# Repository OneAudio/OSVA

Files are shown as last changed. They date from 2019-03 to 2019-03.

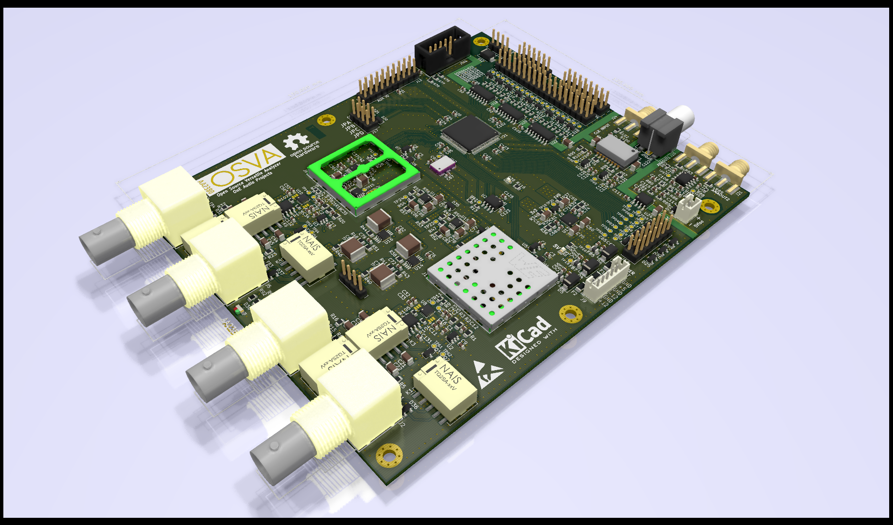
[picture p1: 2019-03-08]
AA2380V1.00_Final/AA2380v1.00_3Dview.png

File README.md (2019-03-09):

# OSVA 
## Open source versatile analyzer (2 Channels 24 bits 1536 kSPS)

The OSVA project is a 2 channels signal analyzer using high resolution SAR ADC (LTC2380-24).
It has been designed to be used as system analyser but using standard digital audio interface.

The OSVA project include 4 sub-design (boards):
-----------------------------------------------
1. AA2380  - 2 channels ADC board : It is the main board.
2. AA10M08 - CPLD digital board : Optional board
3. AAPSU01 - Low noise SMSP board
4. AACMD01 - Command panel board

 The AA2380 main specifications are :
 ------------------------------------
* 2 ADC Channels using LTC2380-24 (or compatible device)
* 24 bits resolution up to 1536 ksps
* 10Vpp full-scale signal sensitivity (default)
* Single-ended or fully differential mode (switchable)
* 2 analog anti-alias filter cuttoff (38.4kHz/384kHz by default)
* On board ultra low jitter clock
* Direct SPDIF stereo output with support up to 192kHz sampling.
* SinC type Digital filter (x1 to x32 selectable).
* isolated 100MHz External clock input (for sampling synchronisation)
* 2 isolated analog output for coherant sampling capability.
* isolated High speed digital interface to connect :
	- AA10M08 dedicated Digital board
	- USB-Streamer from mini-DSP for 4 channels 24/192k to USB
	- SDR-Widget board for 24/192k I2S to USB

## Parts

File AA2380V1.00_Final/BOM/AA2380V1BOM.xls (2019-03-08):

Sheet: Feuille1
Kicad_Projects/AA2380V1/AA2380V1.sch
Ref | Qnty | Value | Footprint | Description | Order code | Distributor | Unit price € | in stock
C1, C2, C3, C4, C5, C6, C7, C9, C10, C16, C17, C18, C19, C20, C25, C32, C39, C40, C41, C42, C43, C48, C55, C57, C88, C89, C90, C91, C92, C93, C94, C95, C97, C100, C101, C102, C103, C105, C106, C109, C111, C118, C119, C124, C125, C127, C129, C131, C132 | 49 | 100nF/16V | Device:Capacitor_SMD:C_0603_1608Metric | Unpolarized capacitor, small symbol | 710-885012206071 | Mouser | 0.03 €
C8, C11, C33, C34, C56, C58, C87, C98, C99, C104, C107, C123 | 12 | 2.2uF/16V | Device:Capacitor_SMD:C_0603_1608Metric | Unpolarized capacitor, small symbol | 81-GRM188C71C225KE1D | Mouser | 0.26 €
C12, C13, C14, C23, C35, C36, C37, C46 | 8 | 10uF/6.3V | Device:Capacitor_SMD:C_0603_1608Metric | Unpolarized capacitor, small symbol | 81-GRM188R60J106KE7D | Mouser | 0.16 €
C15, C38 | 2 | 47uF/6.3V | Device:Capacitor_SMD:C_1210_3225Metric | Unpolarized capacitor, small symbol | 81-GCM32ER70J476KE9L | Mouser | 1.07 €
C21, C30, C44, C53 | 4 | 2.7nF/100V COG | Device:Capacitor_SMD:C_1206_3216Metric | Unpolarized capacitor, small symbol | 80-C1206C272J1G | Mouser | 0.58 €
C22, C31, C45, C54 | 4 | 270pF/100V COG | Device:Capacitor_SMD:C_1206_3216Metric | Unpolarized capacitor, small symbol | 77-VJ1206A271JXBAT | Mouser | 0.20 €
C24, C29, C47, C52 | 4 | 6.8nF/100V COG | Device:Capacitor_SMD:C_1206_3216Metric | Unpolarized capacitor, small symbol | 710-885012008078 | Mouser | 0.48 €
C26, C49 | 2 | 390pF/100V COG | Device:Capacitor_SMD:C_1206_3216Metric | Unpolarized capacitor, small symbol | 77-VJ1206A391JXBMT | Mouser | 0.15 €
C27, C50 | 2 | 3.9nF/100V COG | Device:Capacitor_SMD:C_1206_3216Metric | Unpolarized capacitor, small symbol | 810-C3216C0G2A392J | Mouser | 0.23 €
C28, C51 | 2 | 3.3nF/100V COG | Device:Capacitor_SMD:C_1206_3216Metric | Unpolarized capacitor, small symbol | 710-885012008076 | Mouser | 0.36 €
C59, C60, C69, C70, C77, C84 | 6 | 22uF/16V X7R | Device:Capacitor_SMD:C_1206_3216Metric | Unpolarized capacitor, small symbol | 81-GRM31CC71C226ME1L | Mouser | 0.98 €
C61, C71, C72, C76, C79, C82, C120, C126 | 8 | 10nF/25V X7R | Device:Capacitor_SMD:C_0603_1608Metric | Unpolarized capacitor, small symbol | 710-885012206065 | Mouser | 0.04 €
C62, C63, C64, C65, C66, C67, C68, C74, C110, C113 | 10 | 1uF/25V X7R | Device:Capacitor_SMD:C_0603_1608Metric | Unpolarized capacitor, small symbol | 710-885012106022 | Mouser | 0.08 €
C73, C75, C80, C81 | 4 | 22uF/25V X7R | Device:Capacitor_SMD:C_2220_5650Metric | Unpolarized capacitor, small symbol | 810-C5750X5R1E226M2A | Mouser | 2.15 €
C78, C85 | 2 | 22uF/16V X7R | AA2380:AA2380V1:C_1206_3216Metric_4-PADS | Unpolarized capacitor 4 wires (with sense) | 81-GRM31CC71C226ME1L | Mouser | 0.98 €
C83, C86 | 2 | 22uF/6v3 | Device:Capacitor_SMD:C_1206_3216Metric | Unpolarized capacitor, small symbol | 710-885012108003 | Mouser | 0.66 €
C96, C122, C128, C130 | 4 | 1nF/500V X7R | Device:Capacitor_SMD:C_1206_3216Metric | Unpolarized capacitor, small symbol | 710-885342208006 | Mouser | 0.10 €
C108, C117 | 2 | 10nF 1% | Device:Capacitor_SMD:C_0603_1608Metric | Unpolarized capacitor, small symbol | 81-GRM1885C1H103FA1D | Mouser | 0.25 €
C112, C116 | 2 | 2.7nF 1% | Device:Capacitor_SMD:C_0603_1608Metric | Unpolarized capacitor, small symbol | 81-GRM1885C1H272GA1D | Mouser | 0.24 €
C114, C115 | 2 | 1nF 1% | Device:Capacitor_SMD:C_0603_1608Metric | Unpolarized capacitor, small symbol | 81-GRM1885C1H102FA1D | Mouser | 0.10 €
C121 | 1 | 2u2/16V | Device:Capacitor_SMD:C_0603_1608Metric | Unpolarized capacitor, small symbol | 81-GRM188C81C225KA2D | Mouser | 0.23 €
D1, D2, D36, D37 | 4 | SZNUP2105L | Power_Protection:Package_TO_SOT_SMD:SOT-23 | Dual Line CAN Bus Protector, 24Vrwm, Automotive Grade | 863-SZNUP2105LT1G | Mouser | 0.43 €
D3, D19, D38 | 3 | LED_Small_ALT | Device:LED_SMD:LED_0603_1608Metric | Light emitting diode, small symbol, filled shape | 710-150060GS75000 | Mouser | 0.13 €
D4, D5 | 2 | P4SMA16A | AA2380:Diode_SMD:D_SMA | 400W unidirectional Voltage Suppressor, (SMA) | 576-P4SMA16A | Mouser | 0.49 €
D6 | 1 | P4SMA6.8A | AA2380:Diode_SMD:D_SMA | 400W unidirectional Voltage Suppressor, (SMA) | 576-P4SMA6.8A | Mouser | 0.49 €
D7 | 1 | BAT54C | Diode:Package_TO_SOT_SMD:SOT-23 | dual schottky barrier diode, common cathode | 863-BAT54CLT1G | Mouser | 0.12 €
D8, D35 | 2 | BAV99 | Diode:Package_TO_SOT_SMD:SOT-23 | BAV99 High-speed switching diodes | 863-BAV99LT1G | Mouser | 0.12 €
D9, D10, D11, D13, D14, D15, D16, D17, D18, D20, D21, D22, D23, D24, D25, D26, D27 | 17 | PESD5V0X1BT | AA2380:Package_TO_SOT_SMD:SOT-23 | Dual low capacitance unidirectional ESD Protector, 5Vrwm | 771-PESD5V0X1BT-T/R | Mouser | 0.25 €
D12 | 1 | SMLVT3V3_0 | AA2380:Diode_SMD:D_SMB | 600W unidirectional low voltage (3v3) Transient Voltage Suppressor, DO-201AC (SMB) | 511-SMLVT3V3 | Mouser | 0.58 €
D28, D29, D31, D32, D33 | 5 | MBR0540 | Diode:Diode_SMD:D_SOD-123 | 40V 0.5A Schottky Power Rectifier Diode, SOD-123 | 863-MBR0540T1G | Mouser | 0.27 €
D30, D34 | 2 | APFA3010 | LED:AA2380V1:LED_Kingbright_APFA3010_3x1.5mm_Horizontal | LED RGB, Common Anode, SMD, 3.0x1.5mm, Horizontal | 604-APFA3010LSEEZGKQ | Mouser | 0.79 €
F1 | 1 | 500mA | Device:Fuse:Fuse_1206_3216Metric | Resettable fuse, polymeric positive temperature coefficient, small symbol | 650-NANOC050F/13.2-2 | Mouser | 0.30 €
F2, F3 | 2 | 200mA | Device:Fuse:Fuse_1206_3216Metric | Resettable fuse, polymeric positive temperature coefficient, small symbol | 650-NANOSMDC020F-2 | Mouser | 0.37 €
FB1, FB2, FB3, FB4 | 4 | 600R@100M | AA2380:Inductor_SMD:L_0805_2012Metric_Pad1.15x1.40mm_HandSolder | Ferrite bead | 710-7427920415 | Mouser | 0.19 €
FB5, FB6, FB7 | 3 | 600/100M | AA2380:Inductor_SMD:L_0805_2012Metric_Pad1.15x1.40mm_HandSolder | Ferrite bead | 710-7427920415 | Mouser | 0.19 €
J1, J8 | 2 | RF_Shield_Two_Pieces | Device:AA2380V1:wurth-shield | Two-piece EMI RF shielding cabinet | 710-36103255S | Mouser | 1.29 €
J2, J4, J5, J7 | 4 | Conn_Coaxial | Connector:AA2380V1:BNC_90_73137-5003 | coaxial connector (BNC, SMA, SMB, SMC, Cinch/RCA, ...) | 538-73137-5003 | Mouser | 1.72 €
J9 | 1 | Conn_01x06_Male | Connector:Connector_JST:JST_PH_B6B-PH-K_1x06_P2.00mm_Vertical | Generic connector, single row, 01x06, script generated (kicad-library-utils/schlib/autogen/connector/) | 455-1708-ND | Digikey | 0.29 €
J10 | 1 | Conn_01x04_Female | Connector:Connector_PinHeader_2.54mm:PinHeader_1x04_P2.54mm_Vertical | Generic connector, single row, 01x04, script generated (kicad-library-utils/schlib/autogen/connector/) | 855-M20-7820446 | Mouser | 0.68 €
J11 | 1 | Conn_02x06_Odd_Even | Connector_Generic:Connector_PinHeader_2.54mm:PinHeader_2x06_P2.54mm_Vertical | Generic connector, double row, 02x06, odd/even pin numbering scheme (row 1 odd numbers, row 2 even numbers), script generated (kicad-library-utils/schlib/autogen/connector/) | 855-M20-9760642 | Mouser | 0.38 €
J12 | 1 | Conn_02x10_Odd_Even | Connector_Generic:Connector_PinHeader_2.54mm:PinHeader_2x10_P2.54mm_Vertical | Generic connector, double row, 02x10, odd/even pin numbering scheme (row 1 odd numbers, row 2 even numbers), script generated (kicad-library-utils/schlib/autogen/connector/) | 855-M20-9761042 | Mouser | 0.64 €
J13 | 1 | Conn_02x08_Odd_Even | Connector_Generic:Connector_PinHeader_2.54mm:PinHeader_2x08_P2.54mm_Vertical | Generic connector, double row, 02x08, odd/even pin numbering scheme (row 1 odd numbers, row 2 even numbers), script generated (kicad-library-utils/schlib/autogen/connector/) | 855-M20-9760842 | Mouser | 0.57 €
J14 | 1 | Conn_01x04 | Connector_Generic:Connector_PinHeader_2.54mm:PinHeader_1x04_P2.54mm_Vertical | Generic connector, single row, 01x04, script generated (kicad-library-utils/schlib/autogen/connector/) | 855-M20-9730445 | Mouser | 0.21 €
J16 | 1 | Conn_02x18_Odd_Even | Connector_Generic:Connector_PinHeader_2.54mm:PinHeader_2x18_P2.54mm_Vertical | Generic connector, double row, 02x18, odd/even pin numbering scheme (row 1 odd numbers, row 2 even numbers), script generated (kicad-library-utils/schlib/autogen/connector/) | 855-M20-9761846 | Mouser | 0.80 €
J17 | 1 | Conn_02x04_Odd_Even | Connector_Generic:Connector_PinHeader_2.54mm:PinHeader_2x04_P2.54mm_Vertical | Generic connector, double row, 02x04, odd/even pin numbering scheme (row 1 odd numbers, row 2 even numbers), script generated (kicad-library-utils/schlib/autogen/connector/) | 855-M20-9760442 | Mouser | 0.29 €
J18 | 1 | Conn_02x07_Odd_Even | Connector_Generic:Connector_PinHeader_2.54mm:PinHeader_2x07_P2.54mm_Vertical | Generic connector, double row, 02x07, odd/even pin numbering scheme (row 1 odd numbers, row 2 even numbers), script generated (kicad-library-utils/schlib/autogen/connector/) | 855-M20-9760746 | Mouser | 0.41 €
J19 | 1 | Conn_02x05_Odd_Even | Connector_Generic:Connector_IDC:IDC-Header_2x05_P2.54mm_Vertical | Generic connector, double row, 02x05, odd/even pin numbering scheme (row 1 odd numbers, row 2 even numbers), script generated (kicad-library-utils/schlib/autogen/connector/) | 855-M20-9760542 | Mouser | 0.36 €
J20, J21, J24 | 3 | Conn_Coaxial | Connector:Connector_Coaxial:SMA_Molex_73251-1153_EdgeMount_Horizontal | coaxial connector (BNC, SMA, SMB, SMC, Cinch/RCA, ...) | 538-73251-1150 | Mouser | 3.05 €
J22 | 1 | Conn_02x01 | Connector_Generic:Connector_JST:JST_PH_B2B-PH-K_1x02_P2.00mm_Vertical | Generic connector, double row, 02x01, this symbol is compatible with counter-clockwise, top-bottom and odd-even numbering schemes., script generated (kicad-library-utils/schlib/autogen/connector/) | 455-1704-ND | Digikey | 0.15 €
J23 | 1 | Conn_Coaxial | Connector:AA2380V1:RCA | coaxial connector (BNC, SMA, SMB, SMC, Cinch/RCA, ...) | 806-KLPX-0848A-2-O | Mouser | 0.74 €
K1, K2, K3, K4, K5, K6 | 6 | RELAY_DPDT | AA2380:Relay_SMD:Relay_DPDT_Omron_G6H-2F | Small signal relay, 5V coil ??mW DPDT ??V/ | 769-TQ2SL-5V | Mouser | 3.21 €
Q1, Q2, Q3, Q4 | 4 | BSS138 | Transistor_FET:Package_TO_SOT_SMD:SOT-23 | 50V Vds, 0.22A Id, N-channel MOSFET, SOT-23 | 771-BSS138P215 | Mouser | 0.21 €
R1, R2, R18, R20, R79 | 5 | 1k | Device:Resistor_SMD:R_0805_2012Metric | Resistor | 71-CRCW08051K00FKEB | Mouser | 0.11 €
R3, R21 | 2 | 249 | Device:Resistor_SMD:R_0805_2012Metric | Resistor | 71-CRCW0805-249-E3 | Mouser | 0.11 €
R4, R5, R15, R16, R22, R23, R31, R32 | 8 | 1k 0.5% | Device:Resistor_SMD:R_0805_2012Metric | Resistor | 754-RG2012P-102DT5 | Mouser | 0.19 €
R6, R12, R24, R30 | 4 | 549 0.5% | Device:Resistor_SMD:R_0805_2012Metric | Resistor | 754-RG2012P-5490DT5 | Mouser | 0.19 €
R7, R8, R10, R13, R14, R17, R19, R25, R26, R28, R58, R59, R60, R61, R62, R63, R64, R65, R66, R67, R68, R69, R70, R71, R72, R73, R74, R75 | 28 | 33 | Device:Resistor_SMD:R_0603_1608Metric | Resistor | 71-CRCW0603-33-E3 | Mouser | 0.09 €
R9, R11, R27, R29, R91 | 5 | 10 | Device:Resistor_SMD:R_0603_1608Metric | Resistor | 754-RG1608Q-100DT5 | Mouser | 0.19 €
R33 | 1 | 2K2 | Device:Resistor_SMD:R_0805_2012Metric | Resistor | 71-CRCW08052K20FKEAC | Mouser | 0.17 €
R34, R37, R38, R40, R44, R45, R46, R53, R100 | 9 | NP | Device:Resistor_SMD:R_0805_2012Metric | Resistor |  |  | 0.00 €
R35 | 1 | 33k2 | Device:Resistor_SMD:R_0805_2012Metric | Resistor | CRCW080533K2FKEB | Mouser | 0.11 €
R36 | 1 | 10k7 | Device:Resistor_SMD:R_0805_2012Metric | Resistor | 71-CRCW0805-10.7K-E3 | Mouser | 0.09 €
R39 | 1 | 13k7 | Device:Resistor_SMD:R_0805_2012Metric | Resistor | 71-CRCW0805-13.7K-E3 | Mouser | 0.11 €
R41, R48 | 2 | 32k4 | Device:Resistor_SMD:R_0805_2012Metric | Resistor | 71-CRCW080532K4FKEB | Mouser | 0.09 €
R42 | 1 | 11k | Device:Resistor_SMD:R_0805_2012Metric | Resistor | 71-CRCW080511K0FKEAC | Mouser | 0.17 €
R43, R49, R51, R55, R77, R78 | 6 | 10k | Device:Resistor_SMD:R_0805_2012Metric | Resistor | 71-CRCW080510K0FKEAC | Mouser | 0.17 €
R47 | 1 | 93.1k | Device:Resistor_SMD:R_0805_2012Metric | Resistor | 71-CRCW0805-93.1K-E3 | Mouser | 0.10 €
R50, R56 | 2 | 2.55k | Device:Resistor_SMD:R_0805_2012Metric | Resistor | 71-CRCW0805-2.55K-E3 | Mouser | 0.10 €
R52 | 1 | 33.2k | Device:Resistor_SMD:R_0805_2012Metric | Resistor | 71-CRCW0805-33.2K-E3 | Mouser | 0.11 €
R54 | 1 | 68.1k | Device:Resistor_SMD:R_0805_2012Metric | Resistor | 71-CRCW0805-68.1K-E3 | Mouser | 0.11 €
R57 | 1 | 24.9k | Device:Resistor_SMD:R_0805_2012Metric | Resistor | 71-CRCW0805-24.9K-E3 | Mouser | 0.11 €
R76 | 1 | 1k5 | Device:Resistor_SMD:R_0805_2012Metric | Resistor | 71-CRCW0805-1.5K-E3 | Mouser | 0.11 €
R80, R86 | 2 | 2.61k | Device:Resistor_SMD:R_0603_1608Metric | Resistor | 652-CR0603FX-2611ELF | Mouser | 0.09 €
R81, R87 | 2 | 3.24k | Device:Resistor_SMD:R_0603_1608Metric | Resistor | 71-CRCW06033K24FKEAC | Mouser | 0.12 €
R82, R88 | 2 | 2k | Device:Resistor_SMD:R_0603_1608Metric | Resistor | 71-CRCW06032K00FKEAC | Mouser | 0.15 €
R83, R89 | 2 | 49.9 | Device:Resistor_SMD:R_0805_2012Metric | Resistor | 71-CRCW0805-49.9-E3 | Mouser | 0.11 €
R84, R85 | 2 | 200 | Device:Resistor_SMD:R_0603_1608Metric | Resistor | 71-CRCW0603200RFKEAC | Mouser | 0.09 €
R90, R92, R93, R94, R95, R96 | 6 | 330 | Device:Resistor_SMD:R_0805_2012Metric | Resistor | 71-CRCW0805-330-E3 | Mouser | 0.11 €
R97 | 1 | 243 | Device:Resistor_SMD:R_0805_2012Metric | Resistor | 71-CRCW0805-243-E3 | Mouser | 0.11 €
R98 | 1 | 107 | Device:Resistor_SMD:R_0805_2012Metric | Resistor | 71-CRCW0805-107-E3 | Mouser | 0.11 €
R99, R103 | 2 | 150 | Device:Resistor_SMD:R_0805_2012Metric | Resistor | 71-CRCW0805-150-E3 | Mouser | 0.11 €
R101 | 1 | 75 | Device:Resistor_SMD:R_0805_2012Metric | Resistor | 71-CRCW0805J-75-E3 | Mouser | 0.11 €
R102 | 1 | 0 | Device:Resistor_SMD:R_0805_2012Metric | Resistor | 71-CRCW0805-0-E3 | Mouser | 0.11 €
R104, R105, R106, R107 | 4 | 0 | Device:Resistor_SMD:R_0603_1608Metric | Resistor | 71-CRCW06030000Z0EAC | Mouser | 0.09 €
R108, R109 | 2 | 1k | Device:Resistor_SMD:R_0603_1608Metric | Resistor | 71-CRCW06031K00FKEAC | Mouser | 0.15 €
R110, R111, R112, R113, R114, R115 | 6 | 10k | Device:Resistor_SMD:R_0603_1608Metric | Resistor | 71-CRCW060310K0FKEAC | Mouser | 0.15 €
R116 | 1 | 2k2 | Device:Resistor_SMD:R_0805_2012Metric | Resistor | 71-CRCW0805-2.2K-E3 | Mouser | 0.09 €
T1 | 1 | 749010310 | AA2380:Package_SO:SOIC-16W_7.5x12.8mm_P1.27mm | LAN Transformer 100/100M ,split primary, split secondary | 710-749010310 | Mouser | 4.43 €
U1, U12 | 2 | LTC6655CHMS8-5 | AA2380:Package_SO:MSOP-8_3x3mm_P0.65mm | Low drift precision 5V reference Tc 2ppm/°C | 584-C6655CHMS8-5PBF | Mouser | 6.86 €
U2, U3 | 2 | LT6202CS5 | AA2380:Package_TO_SOT_SMD:SOT-23-5 |  | 584-LT6202CS5#TRMPBF | Mouser | 3.36 €
U4, U6 | 2 | NL17SZ74 | AA2380:Package_SO:VSSOP-8_2.3x2mm_P0.5mm | Ultrafast single DFF Vcc 1.6-5.5V Tpd 2.6ns | 863-NL17SZ74USG | Mouser | 0.38 €
U5, U7 | 2 | NC7SZ04M5X | AA2380:Package_TO_SOT_SMD:SOT-23-5 | single gate UHS Tiny inverter | 512-NC7SZ04M5X | Mouser | 0.43 €
U8, U10 | 2 | ADA4945-1 | AA2380:AA2380V1:LFCSP-16-1EP_3x3mm_P0.5mm_EP1.65x1.65mmThermalviax5_0.3mm | High performance fully differential amplifier ADC driver | 595-THS4541IRG | Mouser | 5.39 €
U9, U11 | 2 | LTC2380CMS-24 | AA2380:Package_SO:MSOP-16_3x4mm_P0.5mm | High performance 24bits 2MSPS SAR ADC with SPI interface | LTC2380CMS-24#PBF | Mouser | 43.76 €
U13 | 1 | TPS7A8701RT | AA2380:AA2380V1:QFN-20-1EP_4x4mm_P0.5mm_EP2.5x2.5mm_ThermalViasx9_0.3mm | Dual 500mA output low noise 3µV LDO | 595-TPS7A8701RTJR | Mouser | 2.03 €
U14 | 1 | TPS7A4901DGN | AA2380:AA2380V1:MSOP-8-1EP_3x3mm_P0.65mm_EP2.54x2.8mm_ThermalViasx5_0.3mm | -200mA -35V ultra low noise LDO voltage regulator, Adjustable Output 1.2_33V | 595-TPS7A4901DGNR | Mouser | 2.49 €
U15, U17 | 2 | LT3042IMSE | AA2380:AA2380V1:MSOP-10-1EP_3x3mm_P0.5mm_EP1.68x1.88mmThermalviax4_0.3mm | 200mA 20V ultra low noise LDO positiverRegulator, Adjustable Output 0_15V | 584-LT3042IMSE#PBF | Mouser | 4.82 €
U16 | 1 | TPS7A3001DG | AA2380:AA2380V1:MSOP-8-1EP_3x3mm_P0.65mm_EP2.54x2.8mm_ThermalViasx5_0.3mm | -200mA -35V ultra low noise LDO negative Regulator, Adjustable Output -1.2_-33V | 595-TPS7A3001DGNR | Mouser | 3.06 €
U18, U20, U22 | 3 | Si8662BB-B-IS1 | AA2380V1-rescue:Package_SO:SOIC-16_3.9x9.9mm_P1.27mm |  | 634-SI8662BB-B-IS1 | Mouser | 2.59 €
U19 | 1 | Si545CAA100M000A | AA2380:AA2380V1:Oscillator_SMD_5x7_Si545 | 1.8-3.3V CMOS SMD ultra low jitter Oscillator (80fs) | 545CAA100M000ABG | Mouser | 12.40 €
U21 | 1 | 5M570ZT100C5N | AA2380:Package_QFP:LQFP-100_14x14mm_P0.5mm | intel/Altera MAXV CPLD with 570 LE | 989-5M570ZT100C5N | Mouser | 6.55 €
U23 | 1 | LT6203CS8 | AA2380:Package_SO:SOIC-8_3.9x4.9mm_P1.27mm | RRIO low noise low power 100MHz dual OPAMP SOIC8 | 584-LT6203CS8#PBF | Mouser | 4.38 €
U24 | 1 | SI8620BB-B-IS | AA2380:Package_SO:SOIC-8_3.9x4.9mm_P1.27mm | Low-Power dual-Channel Digital Isolator, 150Mbps, 2.5-5.5V, 2.5kV isolation, Fail-Safe Low, SOIC-8 | 634-SI8620BB-B-IS | Mouser | 1.00 €
U25 | 1 | DS90LV011A | AA2380:Package_TO_SOT_SMD:SOT-23-5 | LVDS Single High Speed Differential driver, 400Mbps, SOT-23-5 | 926-D90LV011ATMFXNPB | Mouser | 1.06 €
U26 | 1 | DS90LV012A | AA2380:Package_TO_SOT_SMD:SOT-23-5 | LVDS Single High Speed Differential receiver, 400Mbps, SOT-23-5 | 926-S90LV012ATMFNOPB | Mouser | 0.88 €
U27 | 1 | NB3N511 | Oscillator:Package_SO:SOIC-8_3.9x4.9mm_P1.27mm | 3.3V / 5.0V 14 MHz to 200 MHz PLL Clock Multiplier, SOIC-8 | 863-NB3N511DG | Mouser | 4.17 €
U28, U29 | 2 | OPA1632D | AA2380:Package_SO:SOIC-8_3.9x4.9mm_P1.27mm | High performance fully differential amplifier ADC driver | 595-OPA1632DR | Mouser | 4.53 €
 | 357
 |  |  |  |  | Full BOM cost |  | 296.13 €
 |  |  |  |  | Parts in stock (marked as “ok”) |  | 0.00 €
 |  |  |  |  | Partial BOM cost |  | 296.13 €

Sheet: Mouser
Mfr Part Number (Input) | Manufacturer Part Number | Mouser Part Number | Manufacturer Name | Description | Order Quantity | Order Unit Price | Min./Mult. | Availability | Lead Time in Days | Datasheet URL
 |  | 710-885012206071 |  | 100nF/16V | 49
 |  | 81-GRM188C71C225KE1D |  | 2.2uF/16V | 12
 |  | 81-GRM188R60J106KE7D |  | 10uF/6.3V | 8
 |  | 81-GCM32ER70J476KE9L |  | 47uF/6.3V | 2
 |  | 80-C1206C272J1G |  | 2.7nF/100V COG | 4
 |  | 77-VJ1206A271JXBAT |  | 270pF/100V COG | 4
 |  | 710-885012008078 |  | 6.8nF/100V COG | 4
 |  | 77-VJ1206A391JXBMT |  | 390pF/100V COG | 2
 |  | 810-C3216C0G2A392J |  | 3.9nF/100V COG | 2
 |  | 710-885012008076 |  | 3.3nF/100V COG | 2
 |  | 81-GRM31CC71C226ME1L |  | 22uF/16V X7R | 6
 |  | 710-885012206065 |  | 10nF/25V X7R | 8
 |  | 710-885012106022 |  | 1uF/25V X7R | 10
 |  | 810-C5750X5R1E226M2A |  | 22uF/25V X7R | 4
 |  | 81-GRM31CC71C226ME1L |  | 22uF/16V X7R | 2
 |  | 710-885012108003 |  | 22uF/6v3 | 2
 |  | 710-885342208006 |  | 1nF/500V X7R | 4
 |  | 81-GRM1885C1H103FA1D |  | 10nF 1% | 2
 |  | 81-GRM1885C1H272GA1D |  | 2.7nF 1% | 2
 |  | 81-GRM1885C1H102FA1D |  | 1nF 1% | 2
 |  | 81-GRM188C81C225KA2D |  | 2u2/16V | 1
 |  | 863-SZNUP2105LT1G |  | SZNUP2105L | 4
 |  | 710-150060GS75000 |  | LED_Small_ALT | 3
 |  | 576-P4SMA16A |  | P4SMA16A | 2
 |  | 576-P4SMA6.8A |  | P4SMA6.8A | 1
 |  | 863-BAT54CLT1G |  | BAT54C | 1
 |  | 863-BAV99LT1G |  | BAV99 | 2
 |  | 771-PESD5V0X1BT-T/R |  | PESD5V0X1BT | 17
 |  | 511-SMLVT3V3 |  | SMLVT3V3_0 | 1
 |  | 863-MBR0540T1G |  | MBR0540 | 5
 |  | 604-APFA3010LSEEZGKQ |  | APFA3010 | 2
 |  | 650-NANOC050F/13.2-2 |  | 500mA | 1
 |  | 650-NANOSMDC020F-2 |  | 200mA | 2
 |  | 710-7427920415 |  | 600R@100M | 4
 |  | 710-7427920415 |  | 600/100M | 3
 |  | 710-36103255S |  | RF_Shield_Two_Pieces | 2
 |  | 538-73137-5003 |  | Conn_Coaxial | 4
 |  | 855-M20-7820446 |  | Conn_01x04_Female | 1
 |  | 855-M20-9760642 |  | Conn_02x06_Odd_Even | 1
 |  | 855-M20-9761042 |  | Conn_02x10_Odd_Even | 1
 |  | 855-M20-9760842 |  | Conn_02x08_Odd_Even | 1
 |  | 855-M20-9730445 |  | Conn_01x04 | 1
 |  | 855-M20-9761846 |  | Conn_02x18_Odd_Even | 1
 |  | 855-M20-9760442 |  | Conn_02x04_Odd_Even | 1
 |  | 855-M20-9760746 |  | Conn_02x07_Odd_Even | 1
 |  | 855-M20-9760542 |  | Conn_02x05_Odd_Even | 1
 |  | 538-73251-1150 |  | Conn_Coaxial | 3
 |  | 806-KLPX-0848A-2-O |  | Conn_Coaxial | 1
 |  | 769-TQ2SL-5V |  | RELAY_DPDT | 6
 |  | 771-BSS138P215 |  | BSS138 | 4
 |  | 71-CRCW08051K00FKEB |  | 1k | 5
 |  | 71-CRCW0805-249-E3 |  | 249 | 2
 |  | 754-RG2012P-102DT5 |  | 1k 0.5% | 8
 |  | 754-RG2012P-5490DT5 |  | 549 0.5% | 4
 |  | 71-CRCW0603-33-E3 |  | 33 | 28
 |  | 754-RG1608Q-100DT5 |  | 10 | 5
 |  | 71-CRCW08052K20FKEAC |  | 2K2 | 1
 |  | CRCW080533K2FKEB |  | 33k2 | 1
 |  | 71-CRCW0805-10.7K-E3 |  | 10k7 | 1
 |  | 71-CRCW0805-13.7K-E3 |  | 13k7 | 1
 |  | 71-CRCW080532K4FKEB |  | 32k4 | 2
 |  | 71-CRCW080511K0FKEAC |  | 11k | 1
 |  | 71-CRCW080510K0FKEAC |  | 10k | 6
 |  | 71-CRCW0805-93.1K-E3 |  | 93.1k | 1
 |  | 71-CRCW0805-2.55K-E3 |  | 2.55k | 2
 |  | 71-CRCW0805-33.2K-E3 |  | 33.2k | 1
 |  | 71-CRCW0805-68.1K-E3 |  | 68.1k | 1
 |  | 71-CRCW0805-24.9K-E3 |  | 24.9k | 1
 |  | 71-CRCW0805-1.5K-E3 |  | 1k5 | 1
 |  | 652-CR0603FX-2611ELF |  | 2.61k | 2
 |  | 71-CRCW06033K24FKEAC |  | 3.24k | 2
 |  | 71-CRCW06032K00FKEAC |  | 2k | 2
 |  | 71-CRCW0805-49.9-E3 |  | 49.9 | 2
 |  | 71-CRCW0603200RFKEAC |  | 200 | 2
 |  | 71-CRCW0805-330-E3 |  | 330 | 6
 |  | 71-CRCW0805-243-E3 |  | 243 | 1
 |  | 71-CRCW0805-107-E3 |  | 107 | 1
 |  | 71-CRCW0805-150-E3 |  | 150 | 2
 |  | 71-CRCW0805J-75-E3 |  | 75 | 1
 |  | 71-CRCW0805-0-E3 |  | 0 | 1
 |  | 71-CRCW06030000Z0EAC |  | 0 | 4
 |  | 71-CRCW06031K00FKEAC |  | 1k | 2
 |  | 71-CRCW060310K0FKEAC |  | 10k | 6
 |  | 71-CRCW0805-2.2K-E3 |  | 2k2 | 1
 |  | 710-749010310 |  | 749010310 | 1
 |  | 584-C6655CHMS8-5PBF |  | LTC6655CHMS8-5 | 2
 |  | 584-LT6202CS5#TRMPBF |  | LT6202CS5 | 2
 |  | 863-NL17SZ74USG |  | NL17SZ74 | 2
 |  | 512-NC7SZ04M5X |  | NC7SZ04M5X | 2
 |  | 595-THS4541IRG |  | ADA4945-1 | 2
 |  | LTC2380CMS-24#PBF |  | LTC2380CMS-24 | 2
 |  | 595-TPS7A8701RTJR |  | TPS7A8701RT | 1
 |  | 595-TPS7A4901DGNR |  | TPS7A4901DGN | 1
 |  | 584-LT3042IMSE#PBF |  | LT3042IMSE | 2
 |  | 595-TPS7A3001DGNR |  | TPS7A3001DG | 1
 |  | 634-SI8662BB-B-IS1 |  | Si8662BB-B-IS1 | 3
 |  | 545CAA100M000ABG |  | Si545CAA100M000A | 1
 |  | 989-5M570ZT100C5N |  | 5M570ZT100C5N | 1
 |  | 584-LT6203CS8#PBF |  | LT6203CS8 | 1
 |  | 634-SI8620BB-B-IS |  | SI8620BB-B-IS | 1
 |  | 926-D90LV011ATMFXNPB |  | DS90LV011A | 1
 |  | 926-S90LV012ATMFNOPB |  | DS90LV012A | 1
 |  | 863-NB3N511DG |  | NB3N511 | 1
 |  | 595-OPA1632DR |  | OPA1632D | 2

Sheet: Digikey
Mfr Part Number (Input) | Manufacturer Part Number | Mouser Part Number | Manufacturer Name | Description | Order Quantity | Order Unit Price | Min./Mult. | Availability | Lead Time in Days | Datasheet URL
 |  | 455-1708-ND |  | Conn_01x06_Male | 1
 |  | 455-1704-ND |  | Conn_02x01 | 1

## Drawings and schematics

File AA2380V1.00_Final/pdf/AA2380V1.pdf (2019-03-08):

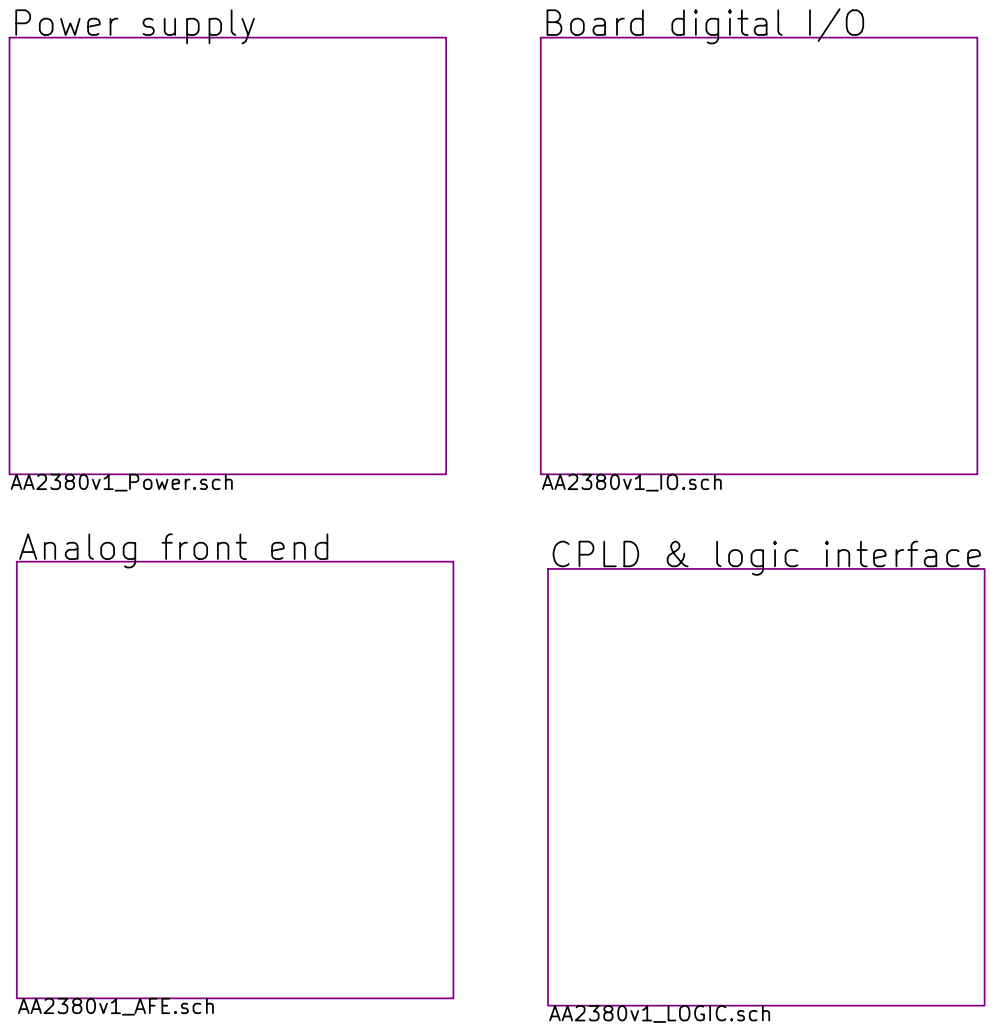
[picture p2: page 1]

Open Source Versatile Analyzer Stand alone dual channels SAR ADCs board Hierarchical view Analog front end

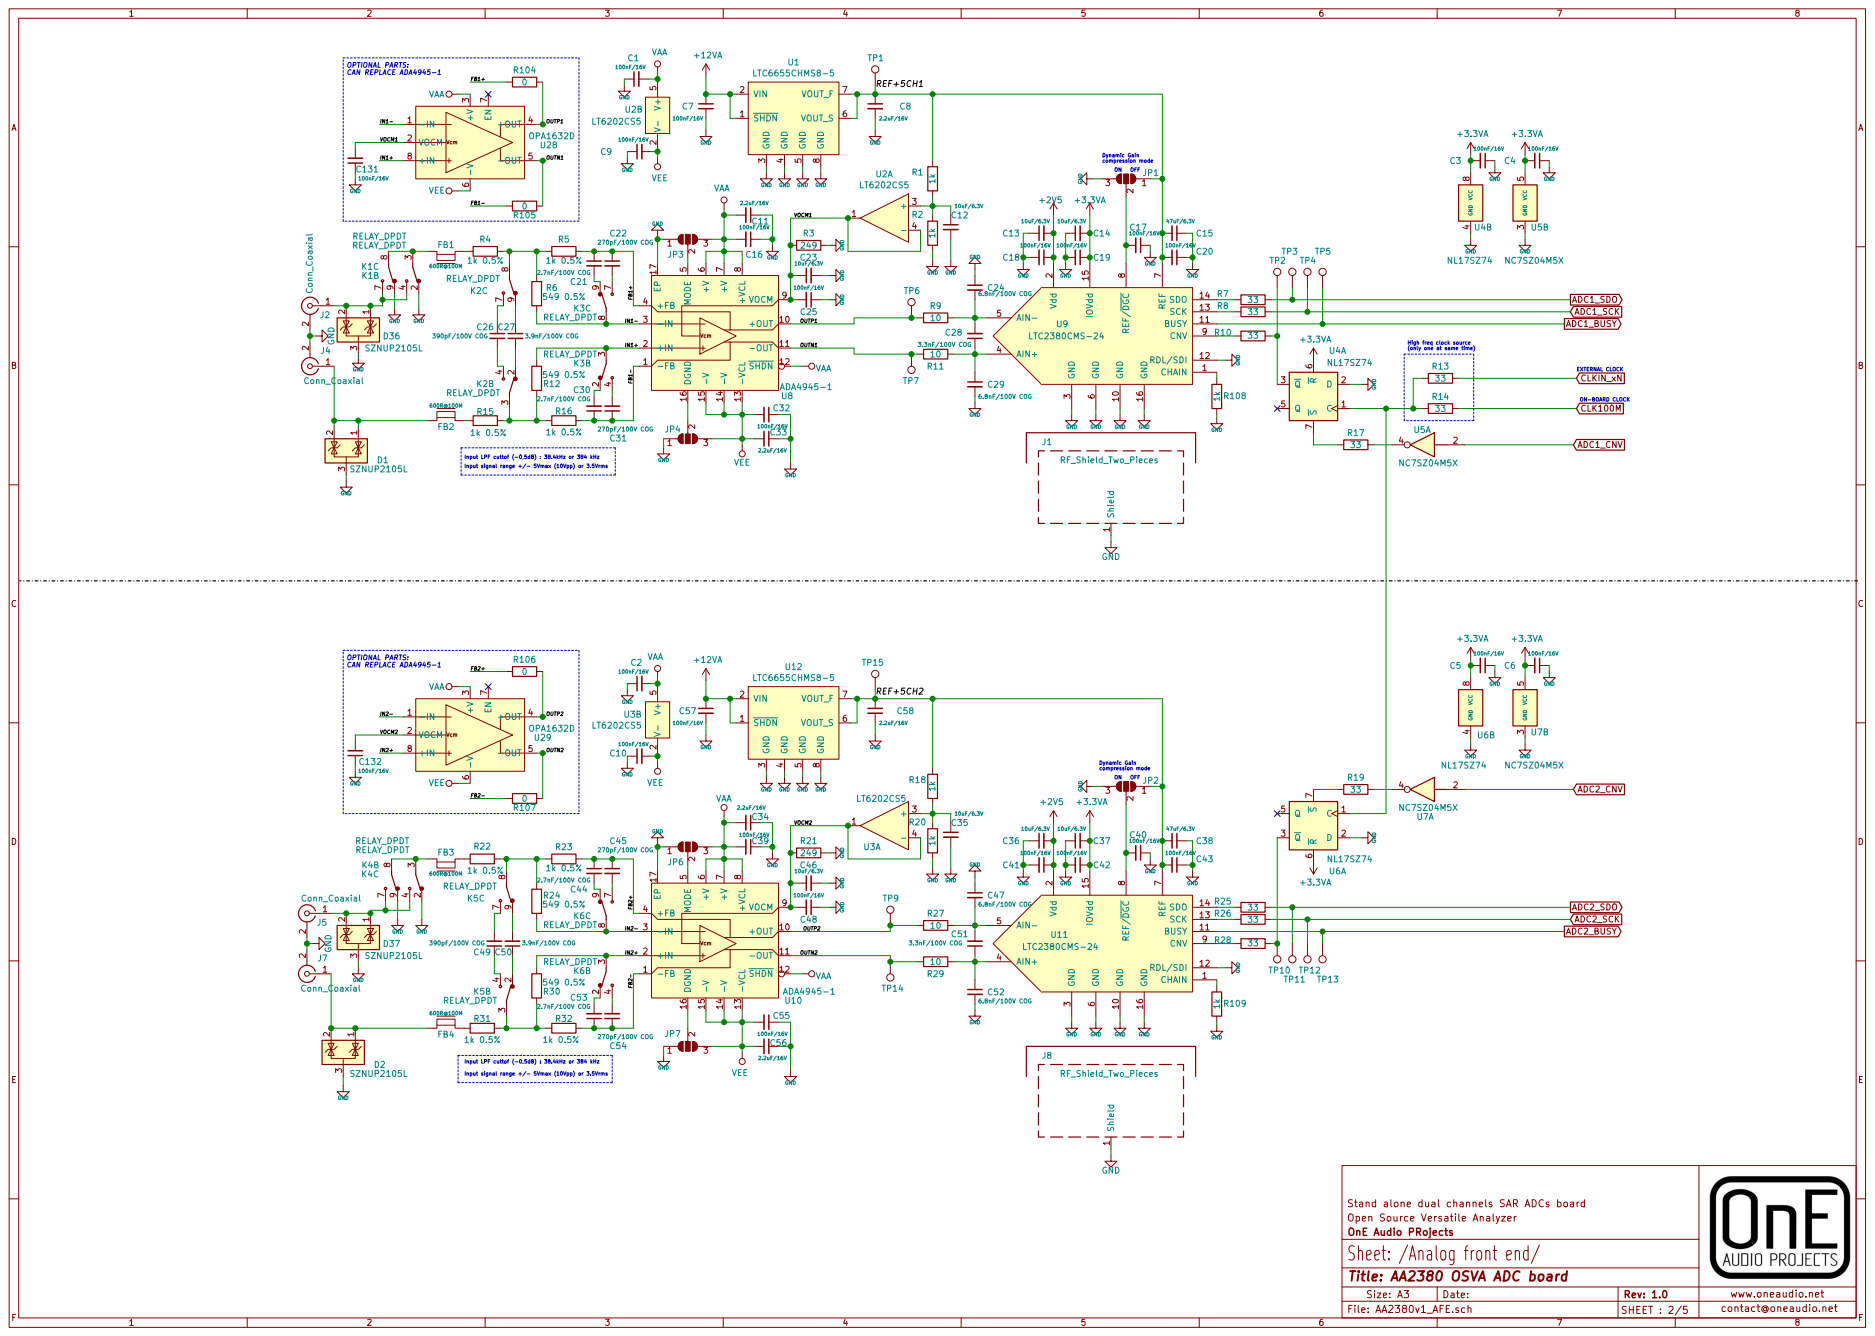
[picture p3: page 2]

OPTIONAL PARTS: CAN REPLACE ADA4945-1

Dynamic Gain
compression mode ON OFF

High freq clock source

Input LPF cuttof (-0,5dB) : 38.4kHz or 384 kHz

Open Source Versatile Analyzer Stand alone dual channels SAR ADCs board
Sheet: /Analog front end/

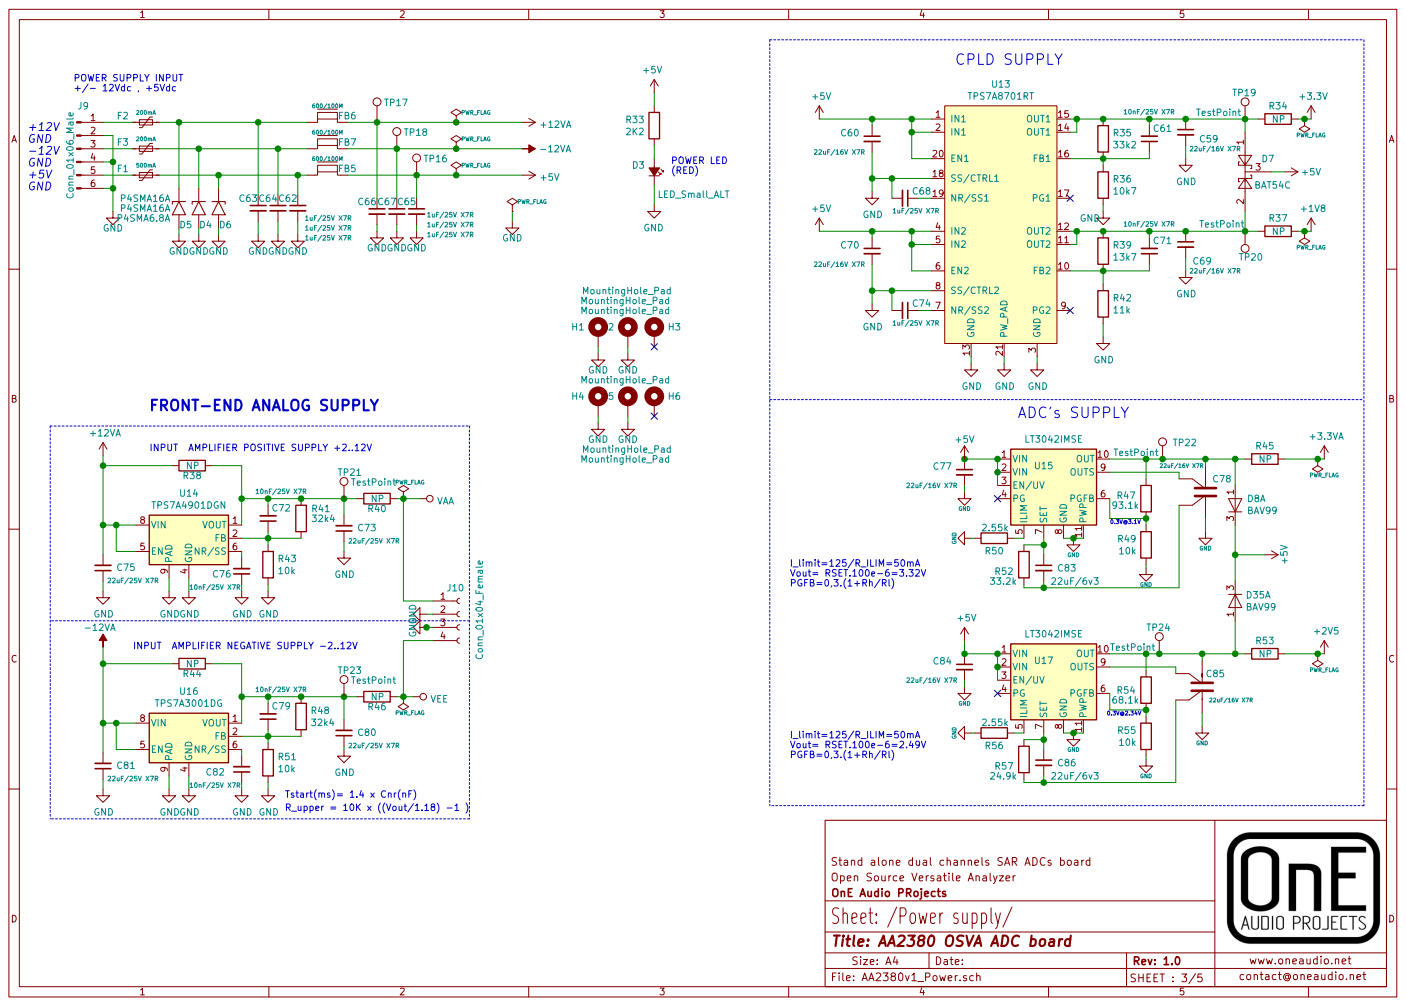
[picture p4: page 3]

(RED) POWER SUPPLY INPUT

INPUT AMPLIFIER POSITIVE SUPPLY +2..12V

4 EN 5 NR/SS 6 VIN 8 PAD

R_upper = 10K x ((Vout/1.18) -1 ) | 4

Open Source Versatile Analyzer Stand alone dual channels SAR ADCs board OnE Audio PRojects

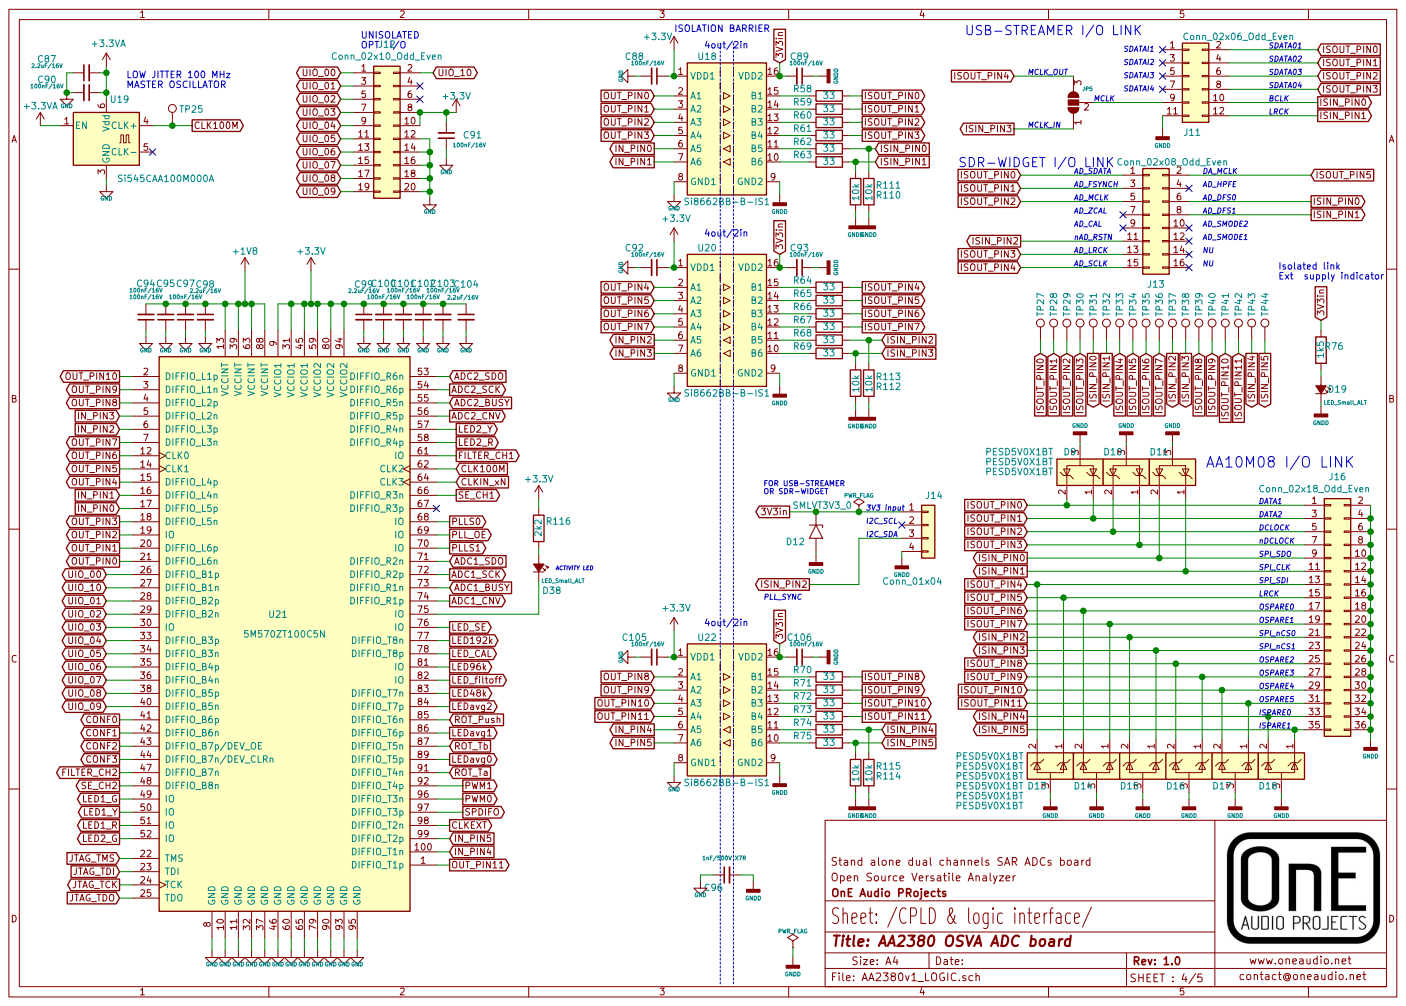
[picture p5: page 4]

LOW JITTER 100 MHz MASTER OSCILLATOR

100nF/16V GND GND GND GND GND +1V8 C98

Isolated link Ext supply indicator

FOR USB-STREAMER OR SDR-WIDGET LED1_Y
IN_PIN1
IN_PIN0

LRCK DATA2 SPI_SDO 7 | 8

SPI_CLK 11 | 12

15 | | 16
17 | | 18
19 | | 20
21 | | 22
23 | | 24
25 | | 26
27 | | 28
29 | | 30
31 | | 32

33 ISPARE0 | | 34

Open Source Versatile Analyzer Stand alone dual channels SAR ADCs board
Sheet: /CPLD & logic interface/

GND GND GND GND GND GND GND GND GND GND GND

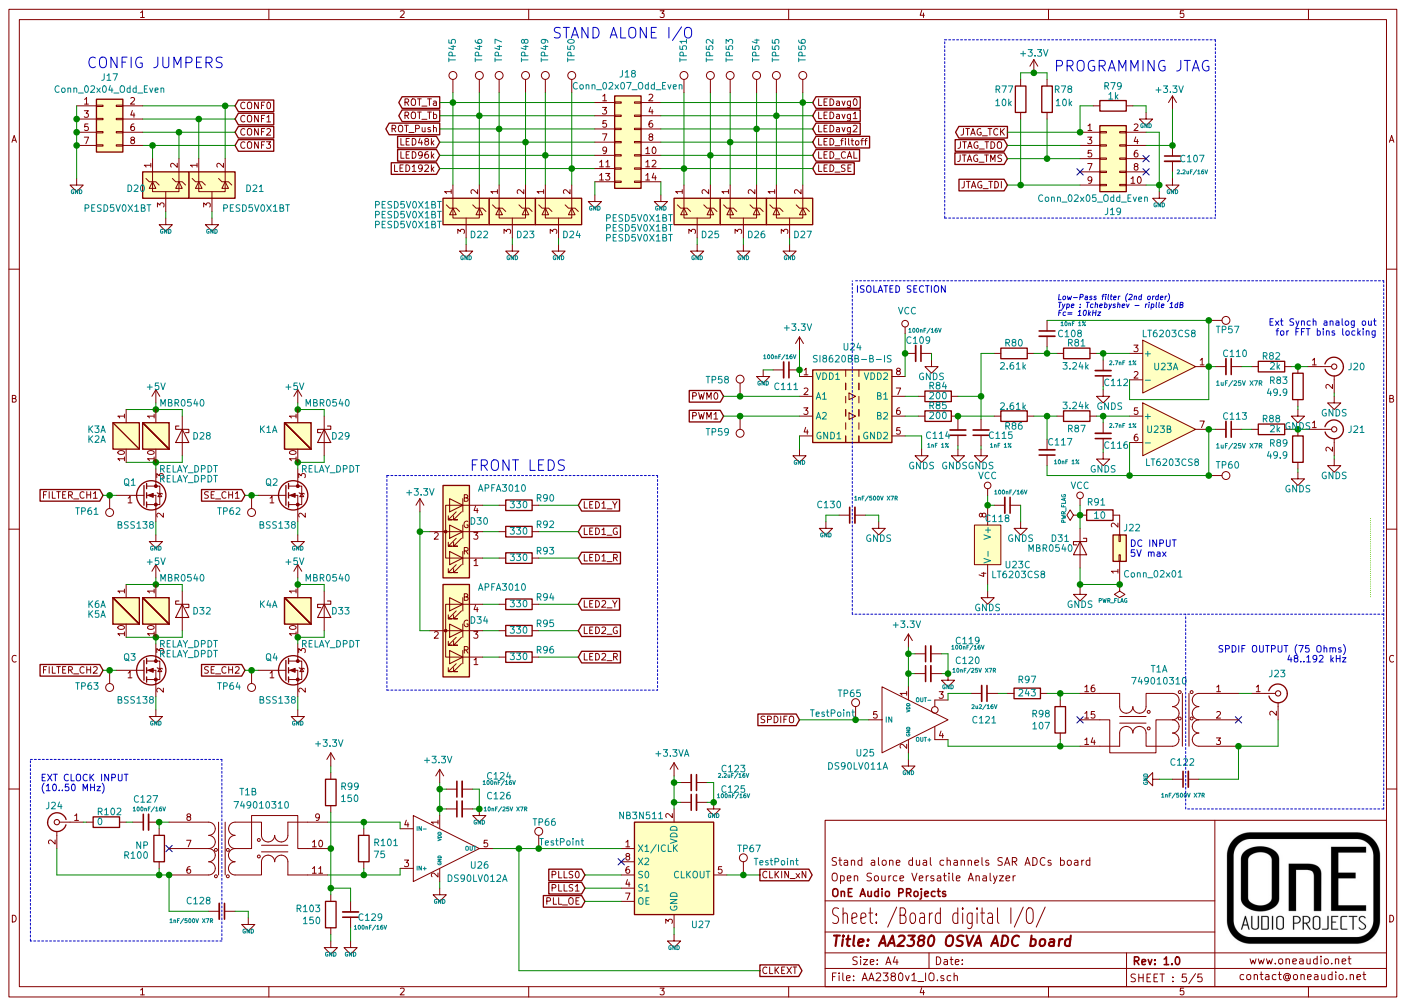
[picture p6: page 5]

Ext Synch analog out
for FFT bins locking

Open Source Versatile Analyzer Stand alone dual channels SAR ADCs board
Sheet: /Board digital I/O/

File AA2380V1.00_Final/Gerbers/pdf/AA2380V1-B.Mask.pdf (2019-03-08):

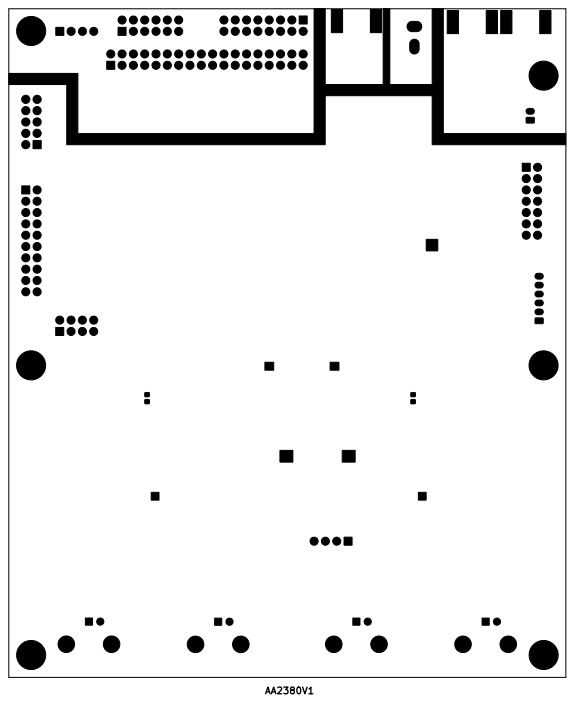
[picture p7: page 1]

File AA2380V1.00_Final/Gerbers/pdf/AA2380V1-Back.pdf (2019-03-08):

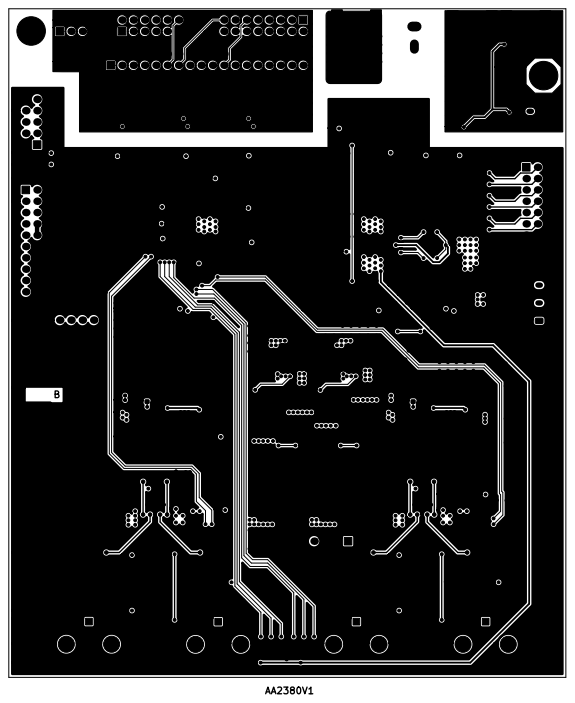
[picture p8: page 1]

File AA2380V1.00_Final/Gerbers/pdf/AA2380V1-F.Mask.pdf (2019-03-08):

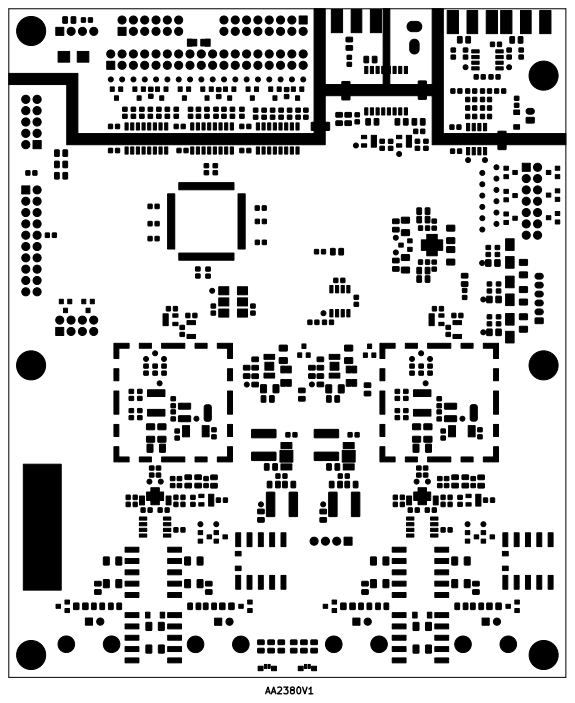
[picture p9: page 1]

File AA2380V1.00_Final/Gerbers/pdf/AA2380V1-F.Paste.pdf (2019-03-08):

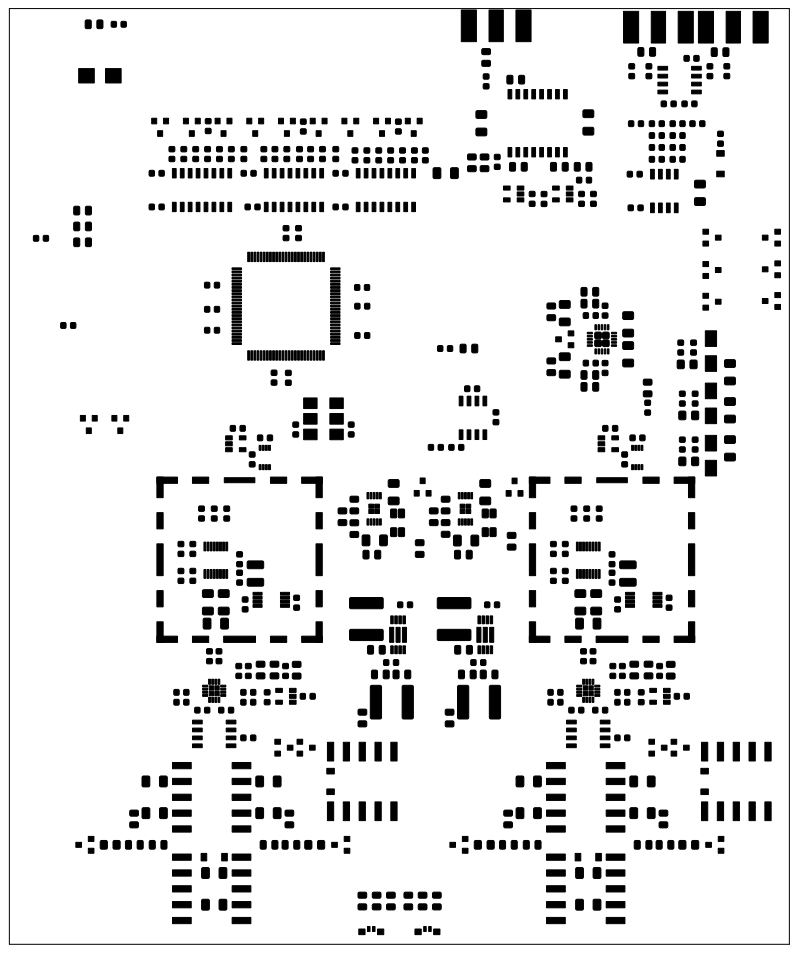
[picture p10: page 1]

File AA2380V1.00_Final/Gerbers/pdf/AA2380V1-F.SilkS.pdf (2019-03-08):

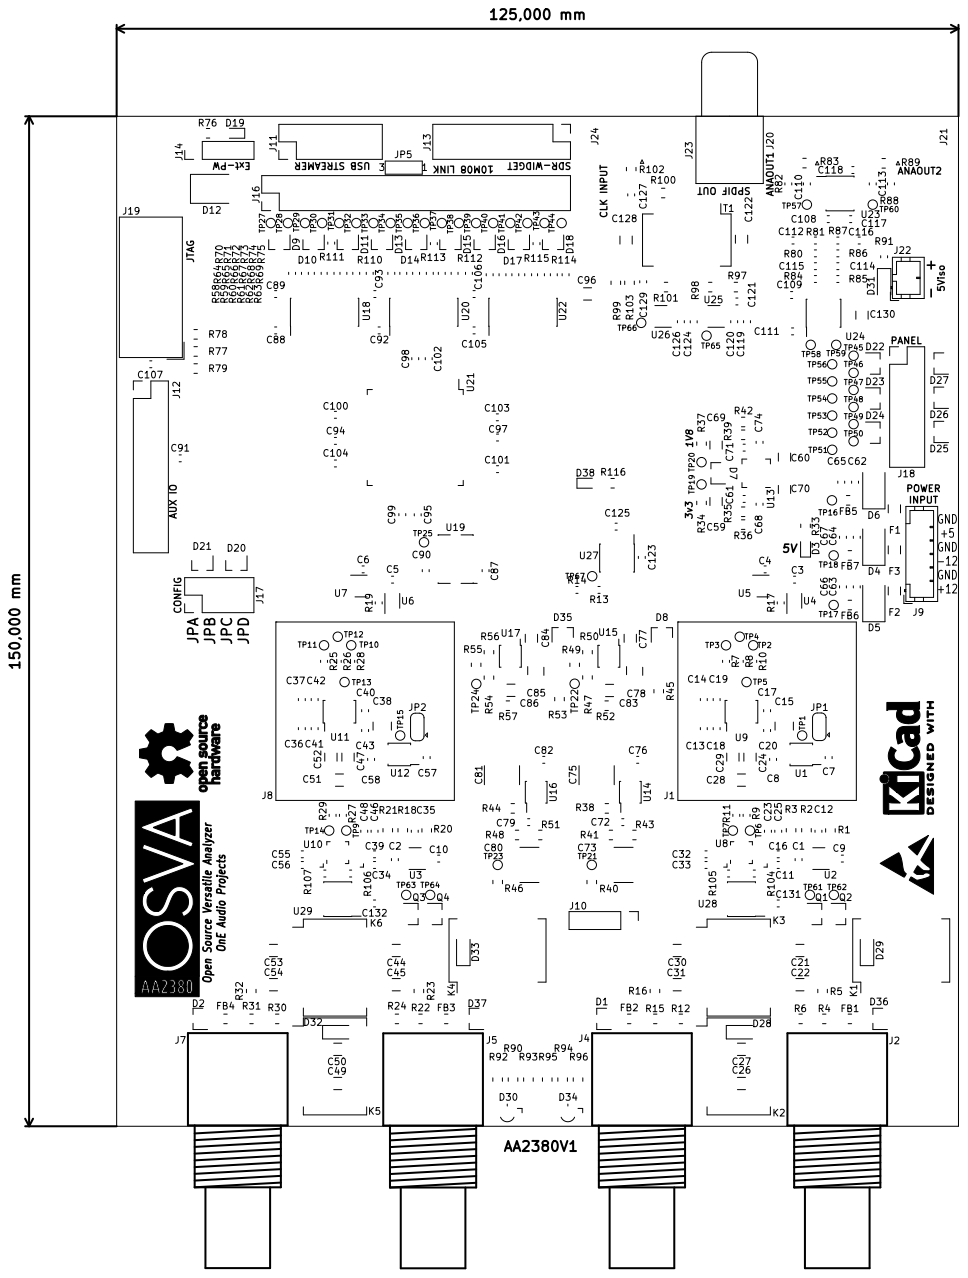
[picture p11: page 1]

+12 Open Source Versatile Analyzer OnE Audio Projects

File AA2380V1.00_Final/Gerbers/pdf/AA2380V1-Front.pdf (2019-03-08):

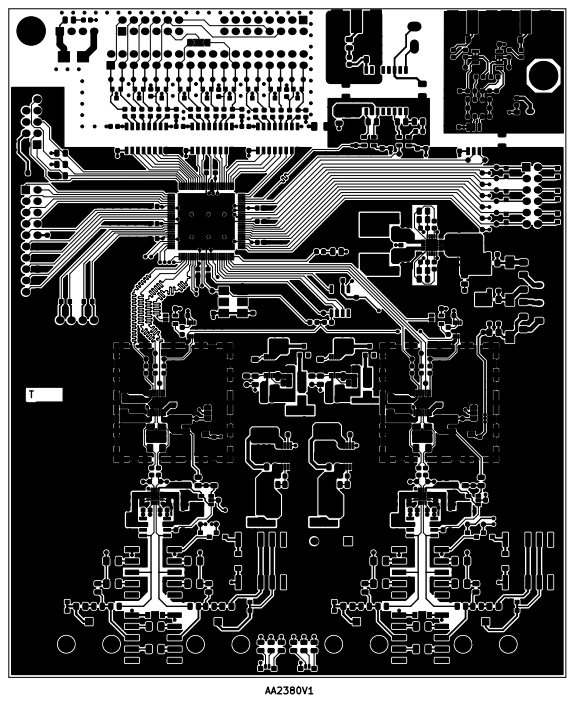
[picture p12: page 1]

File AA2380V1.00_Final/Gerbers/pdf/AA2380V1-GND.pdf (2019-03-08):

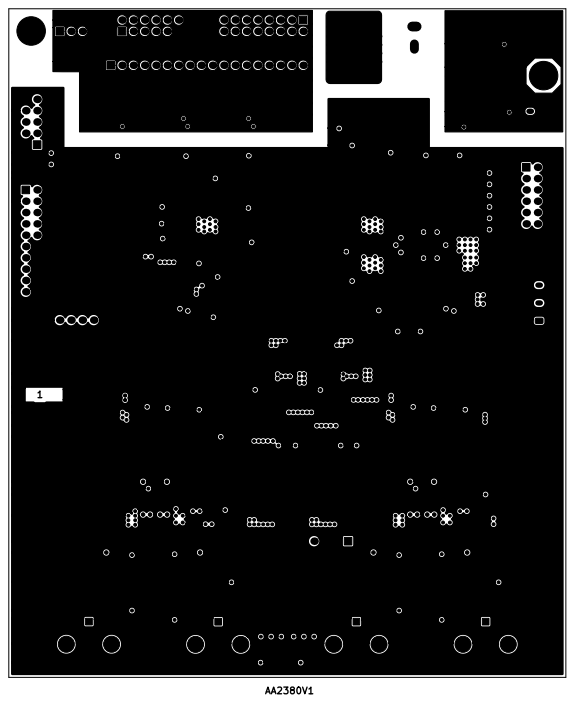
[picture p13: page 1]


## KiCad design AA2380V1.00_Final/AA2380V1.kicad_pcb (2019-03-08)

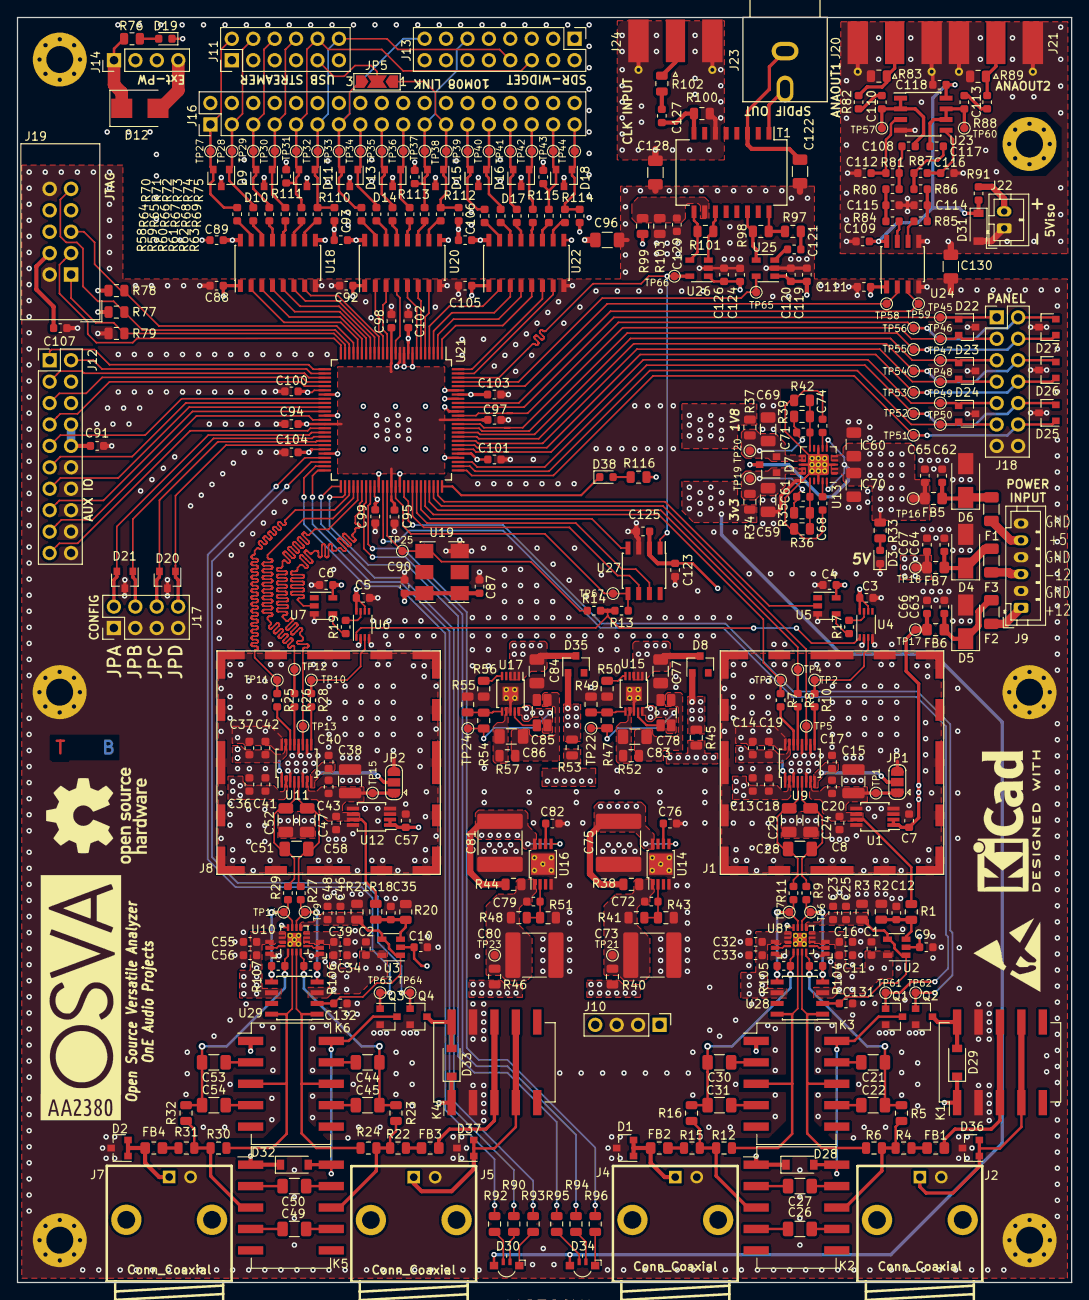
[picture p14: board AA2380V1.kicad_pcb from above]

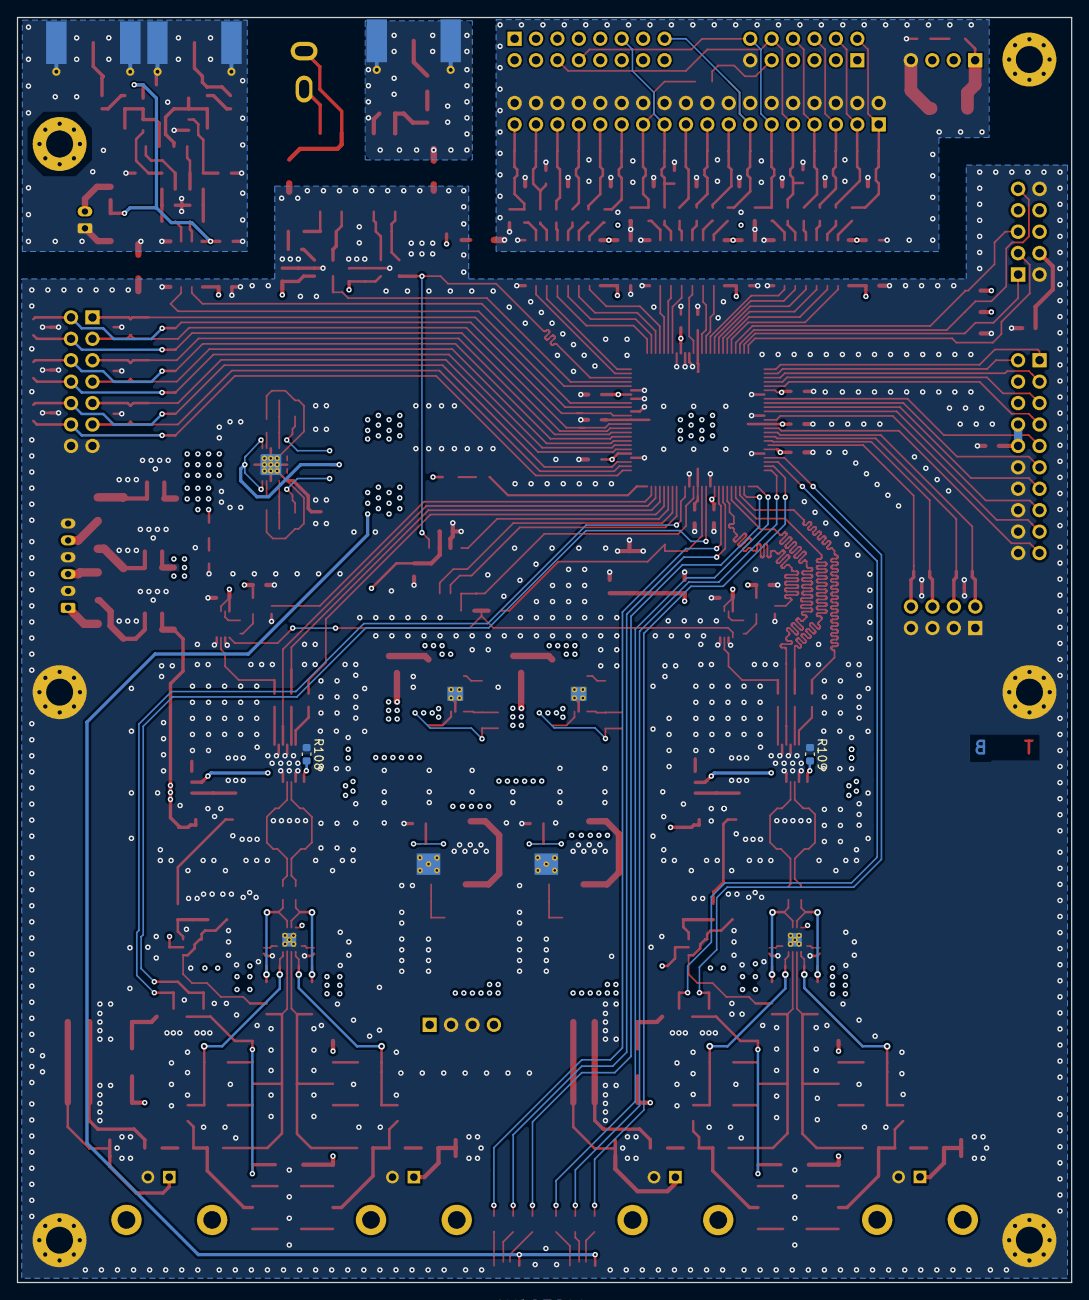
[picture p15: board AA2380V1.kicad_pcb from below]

Board: 4 copper layers, 125.0 x 150.0 mm, 435 parts (2 on the bottom side), 272 nets.

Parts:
C1, C2, C3, C4, C5, C6, C7, C9, C10, C16, C17, C18, C19, C20, C25, C32, C39, C40, C41, C42, C43, C48, C55, C57, C88, C89, C90, C91, C92, C93, C94, C95, C97, C100, C101, C102, C103, C105, C106, C109, C111, C118, C119, C124, C125, C127, C129, C131, C132: 100nF/16V; C_0603_1608Metric
C8, C11, C33, C34, C56, C58, C87, C98, C99, C104, C107, C123: 2.2uF/16V; C_0603_1608Metric
C12, C13, C14, C23, C35, C36, C37, C46: 10uF/6.3V; C_0603_1608Metric
C15, C38: 47uF/6.3V; C_1210_3225Metric
C21, C30, C44, C53: 2.7nF/100V COG; C_1206_3216Metric
C22, C31, C45, C54: 270pF/100V COG; C_1206_3216Metric
C24, C29, C47, C52: 6.8nF/100V COG; C_1206_3216Metric
C26, C49: 390pF/100V COG; C_1206_3216Metric
C27, C50: 3.9nF/100V COG; C_1206_3216Metric
C28, C51: 3.3nF/100V COG; C_1206_3216Metric
C59, C60, C69, C70, C77, C84: 22uF/16V X7R; C_1206_3216Metric
C61, C71, C72, C76, C79, C82, C120, C126: 10nF/25V X7R; C_0603_1608Metric
C62, C63, C64, C65, C66, C67, C68, C74, C110, C113: 1uF/25V X7R; C_0603_1608Metric
C73, C75, C80, C81: 22uF/25V X7R; C_2220_5650Metric
C78, C85: 22uF/16V X7R; C_1206_3216Metric_4-PADS
C83, C86: 22uF/6v3; C_1206_3216Metric
C96, C122, C128, C130: 1nF/500V X7R; C_1206_3216Metric
C108, C117: 10nF 1%; C_0603_1608Metric
C112, C116: 2.7nF 1%; C_0603_1608Metric
C114, C115: 1nF 1%; C_0603_1608Metric
C121: 2u2/16V; C_0603_1608Metric
D1, D2, D36, D37: SZNUP2105L; SOT-23
D3, D19, D38: LED_Small_ALT; LED_0603_1608Metric
D4, D5: P4SMA16A; D_SMA
D6: P4SMA6.8A; D_SMA
D7: BAT54C; SOT-23
D8, D35: BAV99; SOT-23
D9, D10, D11, D13, D14, D15, D16, D17, D18, D20, D21, D22, D23, D24, D25, D26, D27: PESD5V0X1BT; SOT-23
D12: SMLVT3V3_0; D_SMB
D28, D29, D31, D32, D33: MBR0540; D_SOD-123
D30, D34: APFA3010; LED_Kingbright_APFA3010_3x1.5mm_Horizontal
F1: 500mA; Fuse_1206_3216Metric
F2, F3: 200mA; Fuse_1206_3216Metric
FB1, FB2, FB3, FB4: 600R@100M; L_0805_2012Metric_Pad1.15x1.40mm_HandSolder
FB5, FB6, FB7: 600/100M; L_0805_2012Metric_Pad1.15x1.40mm_HandSolder
H1, H2, H3, H4, H5, H6: MountingHole_Pad; MountingHole_3.2mm_M3_Pad_Via
J1, J8: RF_Shield_Two_Pieces; wurth-shield
J2, J4, J5, J7: Conn_Coaxial; BNC_90_73137-5003
J9: Conn_01x06_Male; JST_PH_B6B-PH-K_1x06_P2.00mm_Vertical
J10: Conn_01x04_Female; PinHeader_1x04_P2.54mm_Vertical
J11: Conn_02x06_Odd_Even; PinHeader_2x06_P2.54mm_Vertical
J12: Conn_02x10_Odd_Even; PinHeader_2x10_P2.54mm_Vertical
J13: Conn_02x08_Odd_Even; PinHeader_2x08_P2.54mm_Vertical
J14: Conn_01x04; PinHeader_1x04_P2.54mm_Vertical
J16: Conn_02x18_Odd_Even; PinHeader_2x18_P2.54mm_Vertical
J17: Conn_02x04_Odd_Even; PinHeader_2x04_P2.54mm_Vertical
J18: Conn_02x07_Odd_Even; PinHeader_2x07_P2.54mm_Vertical
J19: Conn_02x05_Odd_Even; IDC-Header_2x05_P2.54mm_Vertical
J20, J21, J24: Conn_Coaxial; SMA_Molex_73251-1153_EdgeMount_Horizontal
J22: Conn_02x01; JST_PH_B2B-PH-K_1x02_P2.00mm_Vertical
J23: Conn_Coaxial; RCA
JP1, JP2: SolderJumper_3_Bridged12; SolderJumper-3_P1.3mm_Open_RoundedPad1.0x1.5mm
JP3, JP4, JP6, JP7: SolderJumper_3_Open; SolderJumper-3_P0.7mm_Open_Pad0.5x1mm_NumberLabels
JP5: SolderJumper_3_Open; SolderJumper-3_P2.0mm_Open_TrianglePad1.0x1.5mm_NumberLabels
K1, K2, K3, K4, K5, K6: RELAY_DPDT; Relay_DPDT_Omron_G6H-2F
Q1, Q2, Q3, Q4: BSS138; SOT-23
R1, R2, R18, R20, R79: 1k; R_0805_2012Metric
R3, R21: 249; R_0805_2012Metric
R4, R5, R15, R16, R22, R23, R31, R32: 1k 0.5%; R_0805_2012Metric
R6, R12, R24, R30: 549 0.5%; R_0805_2012Metric
R7, R8, R10, R13, R14, R17, R19, R25, R26, R28, R58, R59, R60, R61, R62, R63, R64, R65, R66, R67, R68, R69, R70, R71, R72, R73, R74, R75: 33; R_0603_1608Metric
R9, R11, R27, R29, R91: 10; R_0603_1608Metric
R33: 2K2; R_0805_2012Metric
R34, R37, R38, R40, R44, R45, R46, R53, R100: NP; R_0805_2012Metric
R35: 33k2; R_0805_2012Metric
R36: 10k7; R_0805_2012Metric
R39: 13k7; R_0805_2012Metric
R41, R48: 32k4; R_0805_2012Metric
R42: 11k; R_0805_2012Metric
R43, R49, R51, R55, R77, R78: 10k; R_0805_2012Metric
R47: 93.1k; R_0805_2012Metric
R50, R56: 2.55k; R_0805_2012Metric
R52: 33.2k; R_0805_2012Metric
R54: 68.1k; R_0805_2012Metric
R57: 24.9k; R_0805_2012Metric
R76: 1k5; R_0805_2012Metric
R80, R86: 2.61k; R_0603_1608Metric
R81, R87: 3.24k; R_0603_1608Metric
R82, R88: 2k; R_0603_1608Metric
R83, R89: 49.9; R_0805_2012Metric
R84, R85: 200; R_0603_1608Metric
R90, R92, R93, R94, R95, R96: 330; R_0805_2012Metric
R97: 243; R_0805_2012Metric
R98: 107; R_0805_2012Metric
R99, R103: 150; R_0805_2012Metric
R101: 75; R_0805_2012Metric
R102: 0; R_0805_2012Metric
R104, R105, R106, R107: 0; R_0603_1608Metric
R108, R109: 1k; R_0603_1608Metric
R110, R111, R112, R113, R114, R115: 10k; R_0603_1608Metric
R116: 2k2; R_0805_2012Metric
T1: 749010310; SOIC-16W_7.5x12.8mm_P1.27mm
TP1, TP2, TP3, TP4, TP5, TP6, TP7, TP9, TP10, TP11, TP12, TP13, TP14, TP15, TP16, TP17, TP18, TP19, TP20, TP21, TP22, TP23, TP24, TP25, TP27, TP28, TP29, TP30, TP31, TP32, TP33, TP34, TP35, TP36, TP37, TP38, TP39, TP40, TP41, TP42, TP43, TP44, TP45, TP46, TP47, TP48, TP49, TP50, TP51, TP52, TP53, TP54, TP55, TP56, TP57, TP58, TP59, TP60, TP61, TP62, TP63, TP64, TP65, TP66, TP67: TestPoint; TestPoint_Pad_D1.0mm
U1, U12: LTC6655CHMS8-5; MSOP-8_3x3mm_P0.65mm
U2, U3: LT6202CS5; SOT-23-5
U4, U6: NL17SZ74; VSSOP-8_2.3x2mm_P0.5mm
U5, U7: NC7SZ04M5X; SOT-23-5
U8, U10: ADA4945-1; LFCSP-16-1EP_3x3mm_P0.5mm_EP1.65x1.65mmThermalviax5_0.3mm
U9, U11: LTC2380CMS-24; MSOP-16_3x4mm_P0.5mm
U13: TPS7A8701RT; QFN-20-1EP_4x4mm_P0.5mm_EP2.5x2.5mm_ThermalViasx9_0.3mm
U14: TPS7A4901DGN; MSOP-8-1EP_3x3mm_P0.65mm_EP2.54x2.8mm_ThermalViasx5_0.3mm
U15, U17: LT3042IMSE; MSOP-10-1EP_3x3mm_P0.5mm_EP1.68x1.88mmThermalviax4_0.3mm
U16: TPS7A3001DG; MSOP-8-1EP_3x3mm_P0.65mm_EP2.54x2.8mm_ThermalViasx5_0.3mm
U18, U20, U22: Si8662BB-B-IS1; SOIC-16_3.9x9.9mm_P1.27mm
U19: Si545CAA100M000A; Oscillator_SMD_5x7_Si545
U21: 5M570ZT100C5N; LQFP-100_14x14mm_P0.5mm
U23: LT6203CS8; SOIC-8_3.9x4.9mm_P1.27mm
U24: SI8620BB-B-IS; SOIC-8_3.9x4.9mm_P1.27mm
U25: DS90LV011A; SOT-23-5
U26: DS90LV012A; SOT-23-5
U27: NB3N511; SOIC-8_3.9x4.9mm_P1.27mm
U28, U29: OPA1632D; SOIC-8_3.9x4.9mm_P1.27mm

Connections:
3V3in: C89.2, C93.2, C106.2, D12.1, J14.1, R76.2, U18.16, U20.16, U22.16
+1V8: C94.2, C95.2, C97.2, C98.1, R37.1, U21.13, U21.39, U21.63, U21.88
+2V5: C13.2, C18.1, C36.2, C41.1, R53.1, U9.2, U11.2
+3.3VA: C3.2, C4.2, C5.2, C6.2, C14.2, C19.1, C37.2, C42.1, C87.2, C90.1, C123.2, C125.1, R45.1, U4.6, U4.8, U5.5, U6.6, U6.8, U7.5, U9.15, U11.15, U19.1, U19.6, U27.2
+3V3: C88.1, C91.2, C92.1, C99.1, C100.2, C101.2, C102.2, C103.2, C104.1, C105.1, C107.1, C111.1, C119.1, C120.1, C124.1, C126.1, D30.2, D34.2, J12.8, J12.10, J19.4, R34.1, R77.1, R78.1, R99.1, R116.2, U18.1, U20.1, U21.9, U21.31, U21.45, U21.59, U21.80, U21.94, U22.1, U24.1, U25.1, U26.1
+5V: C60.1, C65.1, C70.1, C77.1, C84.1, D7.3, D8.3, D28.1, D29.1, D32.1, D33.1, D35.3, FB5.2, K1.1, K2.1, K3.1, K4.1, K5.1, K6.1, R33.1, TP16.1, U13.1, U13.2, U13.4, U13.5, U13.6, U13.20, U15.1, U15.2, U15.3, U17.1, U17.2, U17.3
+12VA: C7.1, C57.1, C66.1, C75.2, FB6.2, R38.2, TP17.1, U1.1, U1.2, U12.1, U12.2, U14.5, U14.8
-12VA: C67.1, C81.2, FB7.2, R44.2, TP18.1, U16.5, U16.8
/Analog front end/FB1+: C21.1, C22.1, R5.1, R104.2, U8.4
/Analog front end/FB1-: C30.1, C31.1, R16.1, R105.2, U8.1
/Analog front end/FB2+: C44.1, C45.1, R23.1, R106.2, U10.4
/Analog front end/FB2-: C53.1, C54.1, R32.1, R107.2, U10.1
/Analog front end/IN1+: K3.3, R12.2, U8.2, U28.8
/Analog front end/IN1-: K3.8, R6.2, U8.3, U28.1
/Analog front end/IN2+: K6.3, R30.2, U10.2, U29.8
/Analog front end/IN2-: K6.8, R24.2, U10.3, U29.1
/Analog front end/OUTN1: R11.1, R105.1, TP7.1, U8.11, U28.5
/Analog front end/OUTN2: R29.1, R107.1, TP14.1, U10.11, U29.5
/Analog front end/OUTP1: R9.2, R104.1, TP6.1, U8.10, U28.4
/Analog front end/OUTP2: R27.2, R106.1, TP9.1, U10.10, U29.4
/Analog front end/REF+5CH1: C8.1, C15.2, C20.2, JP1.1, R1.2, TP1.1, U1.6, U1.7, U9.7
/Analog front end/REF+5CH2: C38.2, C43.2, C58.1, JP2.1, R18.2, TP15.1, U11.7, U12.6, U12.7
/Analog front end/VOCM1: C23.1, C25.2, C131.2, R3.2, U2.1, U2.4, U8.9, U28.2
/Analog front end/VOCM2: C46.1, C48.2, C132.2, R21.2, U3.1, U3.4, U10.9, U29.2
ADC1_BUSY: TP5.1, U9.11, U21.73
ADC1_CNV: U5.2, U21.74
ADC1_SCK: R8.1, TP4.1, U21.72
ADC1_SDO: R7.1, TP3.1, U21.71
ADC2_BUSY: TP13.1, U11.11, U21.55
ADC2_CNV: U7.2, U21.56
ADC2_SCK: R26.1, TP12.1, U21.54
ADC2_SDO: R25.1, TP11.1, U21.53
CLK100M: R14.1, TP25.1, U19.4, U21.62
CLKEXT: TP66.1, U21.98, U26.5, U27.1
CLKIN_xN: R13.1, TP67.1, U21.64, U27.5
CONF0: D21.2, J17.2, U21.41
CONF1: D21.1, J17.4, U21.42
CONF2: D20.2, J17.6, U21.43
CONF3: D20.1, J17.8, U21.44
FILTER_CH1: Q1.1, TP61.1, U21.61
FILTER_CH2: Q3.1, TP63.1, U21.47
GND: C1.1, C2.1, C3.1, C4.1, C5.1, C6.1, C7.2, C8.2, C9.1, C10.1, C11.1, C12.2, C13.1, C14.1, C15.1, C16.1, C17.1, C18.2, C19.2, C20.1, C23.2, C24.1, C25.1, C29.2, C32.1, C33.1, C34.1, C35.2, C36.1, C37.1, C38.1, C39.1, C40.1, C41.2, C42.2, C43.1, C46.2, C47.1, C48.1, C52.2, C55.1, C56.1, C57.2, C58.2, C59.2, C60.2, C62.2, C63.2, C64.2, C65.2, C66.2, C67.2, C68.2, C69.2, C70.2, C73.1, C74.2, C75.1, C76.1, C77.2, C78.3, C80.1, C81.1, C82.1, C84.2, C85.3, C87.1, C88.2, C90.2, C91.1, C92.2, C94.1, C95.1, C96.1, C97.1, C98.2, C99.2, C100.1, C101.1, C102.1, C103.1, C104.2, C105.2, C107.2, C111.2, C119.2, C120.2, C122.1, C123.1, C124.2, C125.2, C126.2, C128.1, C129.1, C130.1, C131.1, C132.1, D1.3, D2.3, D3.1, D4.2, D5.2, D6.2, D20.3, D21.3, D22.3, D23.3, D24.3, D25.3, D26.3, D27.3, D36.3, D37.3, H1.1, H2.1, H4.1, H5.1, J1.1, J2.2, J4.2, J5.2, J7.2, J8.1, J9.2, J9.4, J9.6, J10.2, J10.3, J12.12, J12.14, J12.16, J12.18, J12.20, J17.1, J17.3, J17.5, J17.7, J18.13, J18.14, J19.2, J19.10, JP1.3, JP2.3, JP3.1, JP4.1, JP6.1, JP7.1, K1.2, K1.9, K4.2, K4.9, Q1.2, Q2.2, Q3.2, Q4.2, R2.1, R3.1, R20.1, R21.1, R36.2, R42.2, R43.2, R49.2, R50.2, R51.2, R55.2, R56.2, R79.2, R103.2, R108.1, R109.1, U1.3, U1.4, U1.5, U1.8, U4.2, U4.4, U5.3, U6.2, U6.4, U7.3, U8.17, U9.3, U9.6, U9.10, U9.12, U9.16, U10.17, U11.3, U11.6, U11.10, U11.12, U11.16, U12.3, U12.4, U12.5, U12.8, U13.3, U13.8, U13.13, U13.18, U13.21, U14.4, U14.9, U15.8, U15.11, U16.4, U16.9, U17.8, U17.11, U18.8, U19.3, U20.8, U21.8, U21.10, U21.11, U21.32, U21.37, U21.46, U21.60, U21.65, U21.79, U21.90, U21.93, U21.95, U22.8, U24.4, U25.2, U26.2, U27.3
GNDD: C89.1, C93.1, C96.2, C106.1, D9.3, D10.3, D11.3, D12.2, D13.3, D14.3, D15.3, D16.3, D17.3, D18.3, D19.1, J11.11, J14.4, J16.2, J16.4, J16.6, J16.8, J16.10, J16.12, J16.14, J16.16, J16.18, J16.20, J16.22, J16.24, J16.26, J16.28, J16.30, J16.32, J16.34, J16.36, R110.2, R111.2, R112.2, R113.2, R114.2, R115.2, U18.9, U20.9, U22.9
GNDS: C109.1, C112.1, C114.1, C115.1, C116.1, C118.1, C130.2, D31.2, J20.2, J21.2, J22.1, R83.2, R89.2, U23.4, U24.5
IN_PIN0: U18.6, U21.17
IN_PIN1: U18.7, U21.16
IN_PIN2: U20.6, U21.6
IN_PIN3: U20.7, U21.5
IN_PIN4: U21.100, U22.6
IN_PIN5: U21.99, U22.7
ISIN_PIN0: D11.2, J11.10, J13.6, J16.9, R62.2, R111.1, TP31.1
ISIN_PIN1: D11.1, J11.12, J13.8, J16.11, R63.2, R110.1, TP32.1
ISIN_PIN2: D15.2, J13.11, J14.3, J16.21, R68.2, R113.1, TP37.1
ISIN_PIN3: D15.1, J16.23, JP5.1, R69.2, R112.1, TP38.1
ISIN_PIN4: D18.2, J16.33, R74.2, R115.1, TP43.1
ISIN_PIN5: D18.1, J16.35, R75.2, R114.1, TP44.1
ISOUT_PIN0: D9.2, J11.2, J13.1, J16.1, R58.2, TP27.1
ISOUT_PIN1: D9.1, J11.4, J13.3, J16.3, R59.2, TP28.1
ISOUT_PIN2: D10.2, J11.6, J13.5, J16.5, R60.2, TP29.1
ISOUT_PIN3: D10.1, J11.8, J13.13, J16.7, R61.2, TP30.1
ISOUT_PIN4: D13.2, J13.15, J16.13, JP5.3, R64.2, TP33.1
ISOUT_PIN5: D13.1, J13.2, J16.15, R65.2, TP34.1
ISOUT_PIN6: D14.2, J16.17, R66.2, TP35.1
ISOUT_PIN7: D14.1, J16.19, R67.2, TP36.1
ISOUT_PIN8: D16.2, J16.25, R70.2, TP39.1
ISOUT_PIN9: D16.1, J16.27, R71.2, TP40.1
ISOUT_PIN10: D17.2, J16.29, R72.2, TP41.1
ISOUT_PIN11: D17.1, J16.31, R73.2, TP42.1
JTAG_TCK: J19.1, R79.1, U21.24
JTAG_TDI: J19.9, R77.2, U21.23
JTAG_TDO: J19.3, U21.25
JTAG_TMS: J19.5, R78.2, U21.22
LED1_G: R92.1, U21.49
LED1_R: R93.1, U21.51
LED1_Y: R90.1, U21.50
LED2_G: R95.1, U21.52
LED2_R: R96.1, U21.58
LED2_Y: R94.1, U21.57
LED48k: D23.2, J18.7, TP48.1, U21.83
LED96k: D24.1, J18.9, TP49.1, U21.81
LED192k: D24.2, J18.11, TP50.1, U21.77
LED_CAL: D25.2, J18.10, TP52.1, U21.78
LED_SE: D25.1, J18.12, TP51.1, U21.76
LED_filtoff: D26.1, J18.8, TP53.1, U21.82
LEDavg0: D27.2, J18.2, TP56.1, U21.89
LEDavg1: D27.1, J18.4, TP55.1, U21.86
LEDavg2: D26.2, J18.6, TP54.1, U21.84
unnamed: C12.1, R1.1, R2.2, U2.3
unnamed: C17.2, JP1.2, U9.8
unnamed: C21.2, K3.9
unnamed: C22.2, K3.7
unnamed: C24.2, C28.2, R9.1, U9.5
unnamed: C26.1, K2.7
unnamed: C26.2, K2.4
unnamed: C27.1, K2.9
unnamed: C27.2, K2.2
unnamed: C28.1, C29.1, R11.2, U9.4
unnamed: C30.2, K3.2
unnamed: C31.2, K3.4
unnamed: C35.1, R18.1, R20.2, U3.3
unnamed: C40.2, JP2.2, U11.8
unnamed: C44.2, K6.9
unnamed: C45.2, K6.7
unnamed: C47.2, C51.2, R27.1, U11.5
unnamed: C49.1, K5.4
unnamed: C49.2, K5.7
unnamed: C50.1, K5.2
unnamed: C50.2, K5.9
unnamed: C51.1, C52.1, R29.2, U11.4
unnamed: C53.2, K6.2
unnamed: C54.2, K6.4
unnamed: C59.1, C61.2, D7.1, R34.2, R35.1, TP19.1, U13.14, U13.15
unnamed: C61.1, R35.2, R36.1, U13.16
unnamed: C62.1, D6.1, F1.1, FB5.1
unnamed: C63.1, D5.1, F2.1, FB6.1
unnamed: C64.1, D4.1, F3.1, FB7.1
unnamed: C68.1, U13.19
unnamed: C69.1, C71.2, D7.2, R37.2, R39.1, TP20.1, U13.11, U13.12
unnamed: C71.1, R39.2, R42.1, U13.10
unnamed: C72.1, R41.2, R43.1, U14.2
unnamed: C72.2, C73.2, R38.1, R40.2, R41.1, TP21.1, U14.1
unnamed: C74.1, U13.7
unnamed: C76.2, U14.6
unnamed: C78.1, D8.1, R45.2, R47.1, TP22.1, U15.10
unnamed: C78.2, U15.9
unnamed: C78.4, C83.2, R52.2
unnamed: C79.1, R48.2, R51.1, U16.2
unnamed: C79.2, C80.2, R44.1, R46.2, R48.1, TP23.1, U16.1
unnamed: C82.2, U16.6
unnamed: C83.1, R52.1, U15.7
unnamed: C85.1, D35.1, R53.2, R54.1, TP24.1, U17.10
unnamed: C85.2, U17.9
unnamed: C85.4, C86.2, R57.2
unnamed: C86.1, R57.1, U17.7
unnamed: C108.1, C110.2, TP57.1, U23.1, U23.2
unnamed: C108.2, R80.2, R81.1
unnamed: C110.1, R82.1
unnamed: C112.2, R81.2, U23.3
unnamed: C113.1, R88.1
unnamed: C113.2, C117.1, TP60.1, U23.6, U23.7
unnamed: C114.2, R85.2, R86.1
unnamed: C115.2, R80.1, R84.2
unnamed: C116.2, R87.2, U23.5
unnamed: C117.2, R86.2, R87.1
unnamed: C121.1, R97.1
unnamed: C121.2, U25.3
unnamed: C122.2, J23.2, T1.3
unnamed: C127.1, R102.1
unnamed: C127.2, R100.1, T1.8
unnamed: C128.2, J24.2, R100.2, T1.6
unnamed: C129.2, R99.2, R103.1, T1.10
unnamed: D1.1, D1.2, FB2.1, J4.1
unnamed: D2.1, D2.2, FB4.1, J7.1
unnamed: D3.2, R33.2
unnamed: D19.2, R76.1
unnamed: D28.2, K2.10, K3.10, Q1.3
unnamed: D29.2, K1.10, Q2.3
unnamed: D30.1, R93.2
unnamed: D30.3, R92.2
unnamed: D30.4, R90.2
unnamed: D32.2, K5.10, K6.10, Q3.3
unnamed: D33.2, K4.10, Q4.3
unnamed: D34.1, R96.2
unnamed: D34.3, R95.2
unnamed: D34.4, R94.2
unnamed: D36.1, D36.2, J2.1, K1.4, K1.7
unnamed: D37.1, D37.2, J5.1, K4.4, K4.7
unnamed: D38.1, U21.75
unnamed: D38.2, R116.1
unnamed: F1.2, J9.5
unnamed: F2.2, J9.1
unnamed: F3.2, J9.3
unnamed: FB1.1, R4.2
unnamed: FB1.2, K1.3, K1.8
unnamed: FB2.2, R15.2
unnamed: FB3.1, R22.2
unnamed: FB3.2, K4.3, K4.8
unnamed: FB4.2, R31.2
unnamed: J11.9, JP5.2
unnamed: J20.1, R82.2, R83.1
unnamed: J21.1, R88.2, R89.1
unnamed: J22.2, R91.2
unnamed: J23.1, T1.1
unnamed: J24.1, R102.2
unnamed: JP3.2, U8.5
unnamed: JP4.2, U8.16
unnamed: JP6.2, U10.5
unnamed: JP7.2, U10.16
unnamed: K2.3, R12.1, R15.1, R16.2
unnamed: K2.8, R4.1, R5.2, R6.1
unnamed: K5.3, R30.1, R31.1, R32.2
unnamed: K5.8, R22.1, R23.2, R24.1
unnamed: R7.2, U9.14
unnamed: R8.2, U9.13
unnamed: R10.1, TP2.1, U4.3
unnamed: R10.2, U9.9
unnamed: R13.2, R14.2, U4.1, U6.1
unnamed: R17.1, U5.4
unnamed: R17.2, U4.7
unnamed: R19.1, U7.4
unnamed: R19.2, U6.7
unnamed: R25.2, U11.14
unnamed: R26.2, U11.13
unnamed: R28.1, TP10.1, U6.3
unnamed: R28.2, U11.9
unnamed: R47.2, R49.1, U15.6
unnamed: R50.1, U15.5
unnamed: R54.2, R55.1, U17.6
unnamed: R56.1, U17.5
unnamed: R58.1, U18.15
unnamed: R59.1, U18.14
unnamed: R60.1, U18.13
unnamed: R61.1, U18.12
unnamed: R62.1, U18.11
unnamed: R63.1, U18.10
unnamed: R64.1, U20.15
unnamed: R65.1, U20.14
unnamed: R66.1, U20.13
unnamed: R67.1, U20.12
unnamed: R68.1, U20.11
unnamed: R69.1, U20.10
unnamed: R70.1, U22.15
unnamed: R71.1, U22.14
unnamed: R72.1, U22.13
unnamed: R73.1, U22.12
unnamed: R74.1, U22.11
unnamed: R75.1, U22.10
unnamed: R84.1, U24.7
unnamed: R85.1, U24.6
unnamed: R97.2, R98.1, T1.16
unnamed: R98.2, T1.14, U25.4
unnamed: R101.1, T1.9, U26.4
unnamed: R101.2, T1.11, U26.3
unnamed: R108.2, U9.1
unnamed: R109.2, U11.1
OUT_PIN0: U18.2, U21.21
OUT_PIN1: U18.3, U21.20
OUT_PIN2: U18.4, U21.19
OUT_PIN3: U18.5, U21.18
OUT_PIN4: U20.2, U21.15
OUT_PIN5: U20.3, U21.14
OUT_PIN6: U20.4, U21.12
OUT_PIN7: U20.5, U21.7
OUT_PIN8: U21.4, U22.2
OUT_PIN9: U21.3, U22.3
OUT_PIN10: U21.2, U22.4
OUT_PIN11: U21.1, U22.5
PLLS0: U21.68, U27.6
PLLS1: U21.70, U27.4
PLL_OE: U21.69, U27.7
PWM0: TP58.1, U21.96, U24.2
PWM1: TP59.1, U21.92, U24.3
ROT_Push: D23.1, J18.5, TP47.1, U21.85
ROT_Ta: D22.1, J18.1, TP45.1, U21.91
ROT_Tb: D22.2, J18.3, TP46.1, U21.87
SE_CH1: Q2.1, TP62.1, U21.66
SE_CH2: Q4.1, TP64.1, U21.48
SPDIFO: TP65.1, U21.97, U25.5
UIO_00: J12.1, U21.26
UIO_01: J12.3, U21.28
UIO_02: J12.5, U21.29
UIO_03: J12.7, U21.30
UIO_04: J12.9, U21.33
UIO_05: J12.11, U21.34
UIO_06: J12.13, U21.35
UIO_07: J12.15, U21.36
UIO_08: J12.17, U21.38
UIO_09: J12.19, U21.40
UIO_10: J12.2, U21.27
VAA: C1.2, C2.2, C11.2, C16.2, C34.2, C39.2, J10.1, JP3.3, JP6.3, R40.1, U2.5, U3.5, U8.6, U8.7, U8.8, U8.12, U10.6, U10.7, U10.8, U10.12, U28.3, U29.3
VCC: C109.2, C118.2, D31.1, R91.1, U23.8, U24.8
VEE: C9.2, C10.2, C32.2, C33.2, C55.2, C56.2, J10.4, JP4.3, JP7.3, R46.1, U2.2, U3.2, U8.13, U8.14, U8.15, U10.13, U10.14, U10.15, U28.6, U29.6
